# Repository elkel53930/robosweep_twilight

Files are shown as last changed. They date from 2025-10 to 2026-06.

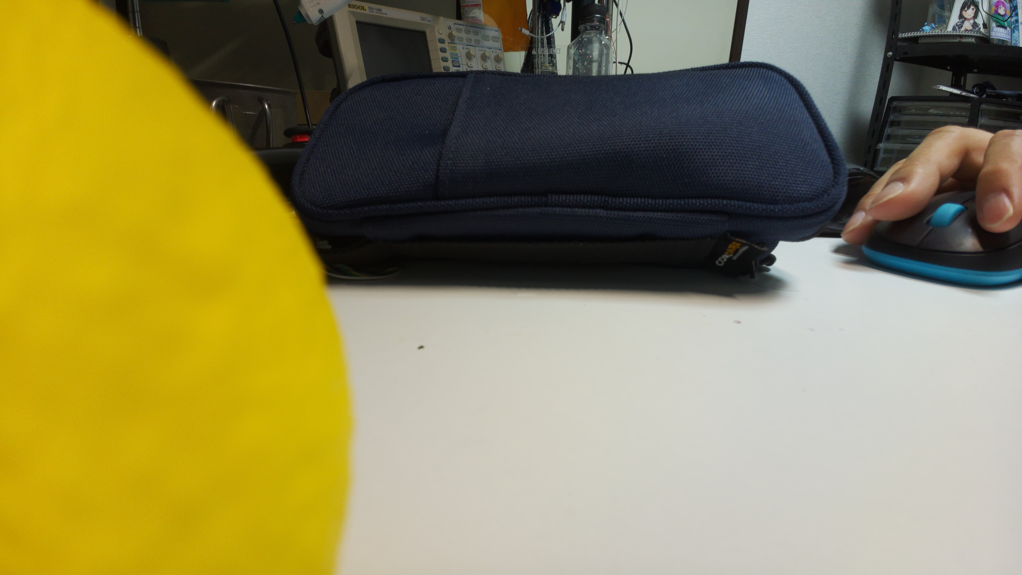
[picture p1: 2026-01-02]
software/rpi/camera_py/test.jpg

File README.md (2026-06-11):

# RoboSweep エージェント Twilight



[RoboSweepプレ大会](https://ntf.or.jp/robosweep/contest/contest2025/)で準優勝したチームからくり工房A:Macのエージェント(ロボット)Twilightのリポジトリです。

CADデータは[こちら](https://a360.co/4pVUIVw))

# ブロック図



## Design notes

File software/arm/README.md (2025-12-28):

# Arduino Nano Arm Board Controller

Arduino Nanoを使用したロボットアーム制御システムです。シリアル通信でサーボモータとDCモータを制御し、INA219センサーによるリアルタイム電流監視とmatplotlibによるグラフ表示機能を提供します。

## システム構成

### Arduino側（arm_board.ino）
- **D8, D9**: PWMサーボモータ（個別デフォルト角度: Servo1=80°, Servo2=180°）
- **A4, A5**: I2C電流センサ（INA219）
- **A1**: バッテリー電圧監視（10:1分圧回路）
- **D3**: NチャンネルMOSFET経由PWMモータ制御（2kHz）
- **センサーデータ送信**: 25ms間隔（40Hz）

### PC側（Python）
- `arm_board_controller.py`: メイン制御クラス
- `test.py`: インタラクティブ制御とファイル実行機能
- `throw_test.py`: 複雑な自動シーケンス実行
- `arm_board_test.py`: 基本機能テスト

## 通信プロトコル

### 制御コマンド（PC → Arduino）
```
S1<angle>       # サーボ1角度設定（即座に移動）(例: S1090 = 90度)
S2<angle>       # サーボ2角度設定（即座に移動）(例: S2180 = 180度)
S1A<angle>,<speed>  # サーボ1角度と速度設定 (例: S1A090,030 = 90度に30°/secで移動)
S2A<angle>,<speed>  # サーボ2角度と速度設定 (例: S2A180,060 = 180度に60°/secで移動)
S1S<speed>      # サーボ1デフォルト速度設定 (例: S1S045 = 45°/sec)
S2S<speed>      # サーボ2デフォルト速度設定 (例: S2S090 = 90°/sec)
M<speed>        # モータ速度設定 (例: M050 = 50%)
STATUS          # センサーデータ要求
STOP            # 緊急停止
```

**速度指定について:**
- 速度は1-180 degrees/secの範囲で指定
- デフォルト速度は180°/sec（最高速度）
- 速度制御は5ms間隔（200Hz）で更新

### 応答（Arduino → PC）
```
OK:<command>:<value>                    # コマンド成功
ERROR:<message>                         # エラー
DATA:<battery>,<current>,<power>        # センサーデータ（25ms毎、40Hz）
DEBUG:<message>                         # デバッグメッセージ
```

## セットアップ

### 必要なライブラリ

#### Arduino側
```cpp
#include <Wire.h>
#include <Servo.h>
#include <Adafruit_INA219.h>  // Adafruit INA219ライブラリが必要
```

Arduino IDEのライブラリマネージャーから「Adafruit INA219」をインストールしてください。

#### Python側
```bash
pip install pyserial matplotlib
```

### ハードウェア接続

1. **サーボモータ**: D8, D9ピンに接続
2. **電流センサ（INA219）**: A4(SDA), A5(SCL)に接続
3. **バッテリー監視**: A1ピンに10:1分圧回路で接続
4. **DCモータ**: D3ピンにMOSFET経由で接続

## 使用方法

### 1. 基本的な制御

```python
from arm_board_controller import ArmBoardController

# コントローラー初期化
controller = ArmBoardController('/dev/ttyUSB0')

if controller.connect():
    # サーボ制御（即座に移動）
    controller.set_servo1_angle(90)   # サーボ1を90度に
    controller.set_servo2_angle(45)   # サーボ2を45度に
    
    # サーボ速度制御
    controller.set_servo1_angle_with_speed(180, 30)  # 180度に30°/secで移動
    controller.set_servo2_angle_with_speed(0, 60)    # 0度に60°/secで移動
    
    # デフォルト速度設定
    controller.set_servo1_speed(45)   # サーボ1のデフォルト速度を45°/sec
    controller.set_servo2_speed(90)   # サーボ2のデフォルト速度を90°/sec
    
    # モータ制御
    controller.set_motor_speed(30)    # モータを30%の速度で回転
    
    # センサーデータ取得
    data = controller.get_latest_sensor_data()
    if data:
        print(f"Battery: {data.battery_voltage:.2f}V")
        print(f"Current: {data.current_mA:.1f}mA")
        print(f"Power: {data.power_mW:.1f}mW")
    
    controller.disconnect()
```

### 2. コンテキストマネージャー使用

```python
with ArmBoardController('/dev/ttyUSB0') as controller:
    controller.set_servo1_angle(90)
    controller.set_motor_speed(50)
    time.sleep(5)
    # 自動的に切断される
```

### 3. リアルタイムデータ監視とグラフ表示

```python
def sensor_callback(data):
    print(f"Battery: {data.battery_voltage:.2f}V, "
          f"Current: {data.current_mA:.1f}mA")

controller = ArmBoardController('/dev/ttyUSB0')
controller.connect()
controller.set_sensor_callback(sensor_callback)

# データは25ms毎にコールバックで受信される（40Hz）
time.sleep(10)
controller.disconnect()
```

### 4. ファイル実行でのリアルタイムプロット

ファイル実行モード時は自動的にmatplotlibグラフが表示されます：
- 上段：電流の生データ（青線）
- 下段：10ポイント移動平均（赤線）
- 時間軸：HH:MM:SS形式
- 自動スケーリング対応

## 新機能

### 1. 高速センサーデータ取得
- センサーデータ送信間隔：25ms（40Hz）
- サーボ制御更新間隔：5ms（200Hz）
- より細かい制御とデータ取得が可能

### 2. ファイル実行システム
- テキストファイルからコマンド読み込み
- ステップバイステップ実行
- 自動ループ機能
- コメント対応（#で始まる行）

### 3. リアルタイムグラフ監視
- matplotlib による電流値の可視化
- 移動平均によるノイズ除去
- 非ブロッキングプロット表示

### 4. 複雑な自動化シーケンス
- 電流値による条件判定
- 移動平均による電流変化の監視
- タイムアウト保護機能

## テストスクリプト

### インタラクティブ制御
```bash
python3 test.py
```

インタラクティブモードでは以下のコマンドが使用できます：
- `s1 90`: サーボ1を90度に設定（即座）
- `s2 180`: サーボ2を180度に設定（即座）
- `s1s 90 30`: サーボ1を90度に30°/secで移動
- `s2s 180 60`: サーボ2を180度に60°/secで移動
- `m 50`: モータを50%の速度に設定
- `stop`: 緊急停止
- `status`: センサーデータ表示
- `file <filename>`: テキストファイルからコマンド実行
- `sample`: サンプルコマンドファイル作成
- `help`: ヘルプ表示
- `quit`: 終了

### ファイル実行機能
```bash
# サンプルファイル作成
>>> sample
# ファイル実行（ステップバイステップ）
>>> file sample_commands.txt
```

ファイル実行モードでは：
- エンターキーで次のコマンドを実行
- 最後まで実行すると自動的にループ
- リアルタイム電流監視グラフ表示
- `q`で終了

### 自動化テストシーケンス
```bash
python3 throw_test.py
```

複雑な動作シーケンスを自動実行：
- サーボの段階的制御
- 電流監視と閾値判定
- 移動平均による電流変化の検出
- タイムアウト保護機能

### 基本制御テスト
```bash
python3 arm_board_test.py
```

## 安全機能

- 角度制限: サーボ角度は0-180度に自動制限
- 速度制限: モータ速度は0-100%に自動制限  
- 緊急停止: `STOP`コマンドですべてのモータを停止
- デフォルト位置復帰: 緊急停止時にServo1=80°、Servo2=180°に復帰
- 接続監視: 通信エラー時の自動復旧
- タイムアウト保護: 長時間処理での自動継続

## ファイルフォーマット

### コマンドファイル例（sample_commands.txt）
```
# Comment lines start with #
s1 180          # Set servo1 to 180 degrees instantly  
s2s 0 10        # Move servo2 to 0 degrees at 10°/sec
s1 45           # Set servo1 to 45 degrees
m 50            # Set motor to 50% speed
m 0             # Stop motor
stop            # Emergency stop
```

## トラブルシューティング

### INA219が見つからない場合
```
Failed to find INA219 chip - continuing without current sensor
```
- 配線を確認（VCC、GND、SDA=A4、SCL=A5）
- I2Cアドレスが0x40であることを確認
- `scanI2CDevices()`でI2Cデバイスをスキャン

### シリアル通信エラー
- ポート名を確認（`/dev/ttyUSB0`, `/dev/ttyACM0`など）
- ボーレートが115200であることを確認
- 他のプログラムがポートを使用していないか確認

### PWM周波数の変更
現在2kHzに設定されています。変更する場合は`setupMotorPWM()`関数を編集してください。

## ライセンス

このプロジェクトはMITライセンスの下で公開されています。

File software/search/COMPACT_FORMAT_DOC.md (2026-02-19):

# マイクロマウス迷路データ コンパクト形式 仕様書

## 概要

本ドキュメントでは、マイクロマウス迷路データの圧縮保存・転送を目的とした2つのコンパクト形式について説明します。

- **コンパクト形式**: 16進数ベースで中程度の圧縮率を実現し、デバッグ時にも内容を確認できる形式
- **ウルトラコンパクト形式**: バイナリ+Base64でMaximum圧縮を実現し、ネットワーク転送に最適化された形式

## 従来形式との比較

| 形式 | サイズ例（16x16迷路） | 圧縮率 | 可読性 | 用途 |
|---|---|---|---|---|
| 従来ASCII | 1122 bytes | 100% | ★★★ | 人間による編集・確認 |
| コンパクト | 528 bytes | 47.1% | ★☆☆ | デバッグ可能な圧縮保存 |
| ウルトラコンパクト | 352 bytes | 31.4% | ☆☆☆ | 最大圧縮・ネットワーク転送 |

---

## 1. コンパクト形式（Compact Format）

### 仕様

**対象サイズ**: 最大99x99の迷路まで対応

**フォーマット構造**:
```
[サイズ2桁][壁データ][|][観測データ][|G座標4桁][|S座標5桁]
```

### エンコード詳細

#### ヘッダー部
- **サイズ**: 2桁の10進数（ゼロパディング）
  - 例: `16` → 16x16迷路

#### 壁データ部
各セルの壁情報を4ビットの16進数1文字で表現：
```
ビット配置: [WEST|SOUTH|EAST|NORTH]
```
- bit 0 (0x1): 北の壁
- bit 1 (0x2): 東の壁  
- bit 2 (0x4): 南の壁
- bit 3 (0x8): 西の壁

セルの走査順序: `y=0,x=0` → `y=0,x=1` → ... → `y=size-1,x=size-1`

#### 観測データ部
壁データと同じ形式で、各方向が観測済みかどうかを記録

#### オプション部
- **ゴール**: `|G` + X座標2桁 + Y座標2桁
- **スタート**: `|S` + X座標2桁 + Y座標2桁 + 向き1桁

### エンコード例

```python
# 16x16迷路の例
"16c555545555455456ac55695556ad7a|eaaac515556a8542aaaa955447abafaaaaa|G0707|S00011"
```

分解すると:
- `16`: 16x16迷路
- `c555...`: 壁データ（256文字）
- `|eaaa...`: 観測データ（256文字） 
- `|G0707`: ゴール座標(7,7)
- `|S0001`: スタート座標(0,0)、向き1（東）

### 使用関数

```python
# エンコード
compact_str = write_maze_compact(known_walls, observed, goal, start_pose)

# デコード  
known_walls, observed, goal, start_pose = read_maze_compact(compact_str)

# Explorer経由
explorer = AdachiExplorer()
compact_data = explorer.export_compact()
goal = explorer.import_compact(compact_data)
```

---

## 2. ウルトラコンパクト形式（Ultra-Compact Format）

### 仕様

**対象サイズ**: 最大255x255の迷路まで対応

**エンコード**: バイナリデータをBase64エンコード

### バイナリ構造

```
[サイズ1byte][フラグ1byte][壁データ][観測データ][オプション]
```

#### ヘッダー部
1. **サイズ**: 1バイト（0-255）
2. **フラグ**: 1バイト
   - bit 0 (0x01): ゴール情報有り
   - bit 1 (0x02): スタート情報有り（デフォルトでない場合）
   - bit 2-7: 予約

#### データ部
**ビットパッキング**: 各セル4ビットを効率的にバイト境界で詰め込み

セル毎の壁情報（4ビット）:
```
[bit3:西|bit2:南|bit1:東|bit0:北]
```

パッキング例（16x16 = 256セル）:
- 256セル × 4ビット = 1024ビット = 128バイト（壁）
- 256セル × 4ビット = 1024ビット = 128バイト（観測）

#### オプション部
フラグに応じて追加:
- **ゴール** (2バイト): X座標 + Y座標
- **スタート** (3バイト): X座標 + Y座標 + 向き

### エンコード例

```python
# Base64エンコード結果例
"EANcVUVVVVRFZcpVllVl2qeuqlxRVaZYJKqqWUV0uvqqqopFpspRcaqrqq+qqlxVgiWapqqqy2Srr1..."
```

バイナリ構造:
```
0x10: サイズ（16）
0x03: フラグ（ゴール+スタート有り）
0x5c, 0x55, ...: ビットパックされた壁データ（128バイト）
0xea, 0xaa, ...: ビットパックされた観測データ（128バイト）  
0x07, 0x07: ゴール座標(7,7)
0x00, 0x00, 0x01: スタート座標(0,0)、向き1
```

### 使用関数

```python
# エンコード
ultra_str = write_maze_ultracompact(known_walls, observed, goal, start_pose)

# デコード
known_walls, observed, goal, start_pose = read_maze_ultracompact(ultra_str)

# Explorer経由
explorer = AdachiExplorer()
ultra_data = explorer.export_ultracompact()
goal = explorer.import_ultracompact(ultra_data)
```

---

## 3. 利用シーン別推奨事項

### コンパクト形式を推奨する場面
- ✅ ログファイルの圧縮保存
- ✅ デバッグ時に内容を確認したい場合
- ✅ ヒューマンリーダブルな圧縮が必要
- ✅ 中程度の圧縮で十分な場合

### ウルトラコンパクト形式を推奨する場面  
- ✅ ネットワーク経由での迷路データ転送
- ✅ 大量の迷路データのアーカイブ
- ✅ メモリ制約が厳しい組み込みシステム
- ✅ 最大限の圧縮率が必要な場合
- ✅ データベースでの大量保存

### 従来ASCII形式を推奨する場面
- ✅ 人間が直接編集する迷路ファイル
- ✅ 迷路の視覚的確認が必要
- ✅ 既存ツールとの互換性が必要
- ✅ 学習・デバッグ目的での利用

---

## 4. 実装上の注意点

### エラーハンドリング
```python
try:
    data = write_maze_compact(walls, obs, goal, pose)
    walls, obs, goal, pose = read_maze_compact(data)
except ValueError as e:
    print(f"フォーマットエラー: {e}")
```

### サイズ制限
- **コンパクト形式**: 99x99まで
- **ウルトラコンパクト形式**: 255x255まで
- 制限を超えるとValueErrorが発生

### パフォーマンス特性
- **エンコード**: O(size²) 
- **デコード**: O(size²)
- **メモリ使用量**: O(size²)

---

## 5. テスト・検証

テストスクリプトでの検証:
```bash
cd software/search
python3 test_step_solver.py --compact-test maze_data/file.txt --verbose
```

出力例:
```
[INFO] Compact encoded (528 bytes): 16c555545555455456ac...
[INFO] Ultra-compact encoded (352 bytes): EANcVUVVVVRFZcpV...
[INFO] Size comparison: original=1122 bytes, compact=528 bytes (47.1%), ultra-compact=352 bytes (31.4%)
```

### 検証内容
1. エンコード/デコードの可逆性
2. 壁データの完全性
3. 観測データの完全性  
4. ゴール・スタート位置の保持
5. 圧縮率の測定

---

## 6. 今後の拡張可能性

### 追加可能な機能
- 距離情報の埋め込み
- 探索履歴の圧縮保存
- カスタムメタデータの追加
- より高度な圧縮アルゴリズムの適用

### 互換性の維持
- フォーマットバージョニング
- 下位互換性の保証
- 段階的な機能追加

---

## リファレンス

### 関数一覧

| 関数名 | 説明 | 戻り値 |
|---|---|---|
| `write_maze_compact()` | コンパクト形式エンコード | str |
| `read_maze_compact()` | コンパクト形式デコード | tuple |
| `write_maze_ultracompact()` | ウルトラコンパクト形式エンコード | str |
| `read_maze_ultracompact()` | ウルトラコンパクト形式デコード | tuple |
| `BaseExplorer.export_compact()` | エクスプローラーからエクスポート | str |
| `BaseExplorer.import_compact()` | エクスプローラーへインポート | tuple[int,int]\|None |
| `BaseExplorer.export_ultracompact()` | ウルトラコンパクトエクスポート | str |
| `BaseExplorer.import_ultracompact()` | ウルトラコンパクトインポート | tuple[int,int]\|None |

### ファイル構成
- `micromouse_algorithms.py`: メイン実装
- `test_step_solver.py`: テスト・検証機能
- このドキュメント: `COMPACT_FORMAT_DOC.md`

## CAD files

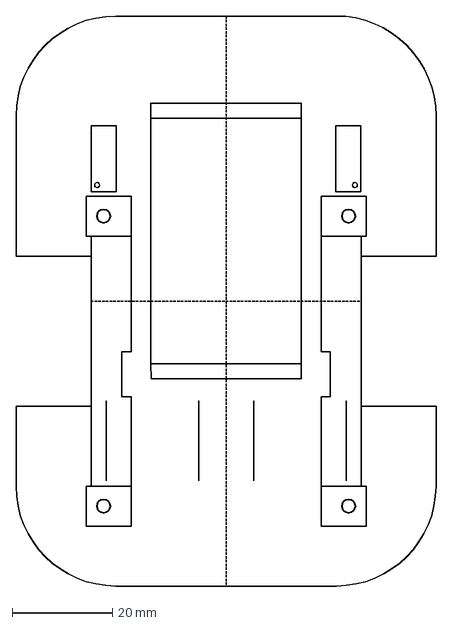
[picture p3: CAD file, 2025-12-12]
elec/main_board/main_board_outline.dxf
84.0 x 114.0 mm

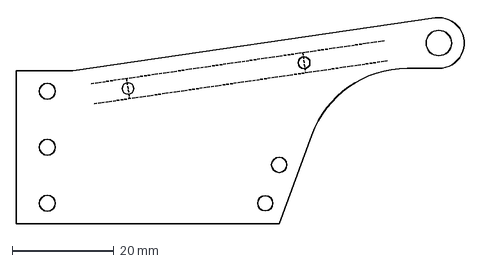
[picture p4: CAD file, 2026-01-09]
elec/arm_board/arm_board_outline.dxf
88.4 x 40.7 mm

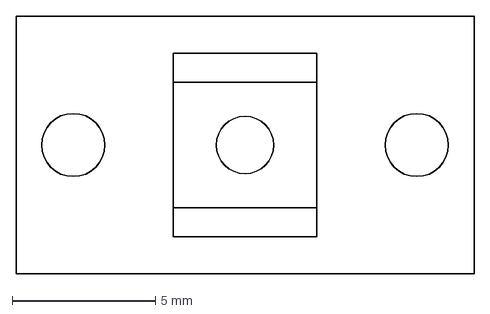
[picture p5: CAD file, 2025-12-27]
elec/sub_boards/encoder_board_outline.dxf
16.0 x 9.00 mm

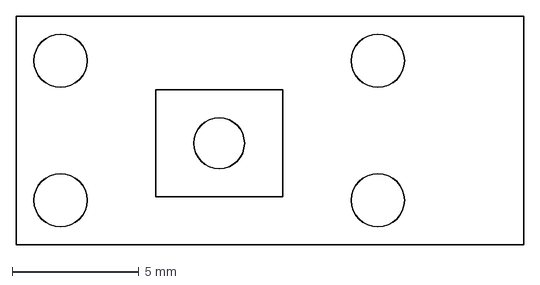
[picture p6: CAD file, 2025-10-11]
elec/main_board/encoder_board_outline.dxf
20.0 x 9.00 mm

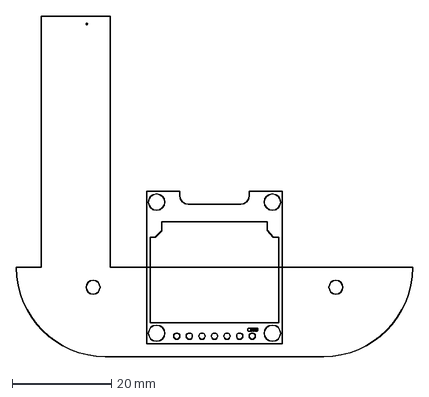
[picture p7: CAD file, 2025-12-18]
elec/sub_boards/if_sub_board_outline.dxf
80.0 x 68.6 mm

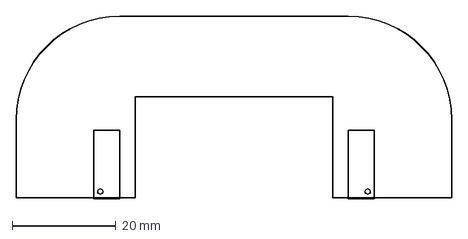
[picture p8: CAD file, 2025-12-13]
elec/sub_boards/sensor_sub_board_outline.dxf
84.0 x 35.2 mm

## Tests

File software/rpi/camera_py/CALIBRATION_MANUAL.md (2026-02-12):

# ボール検出キャリブレーションマニュアル

## 概要

`manual_calibration.py`は、カメラとボール検出アルゴリズムのキャリブレーションデータを収集するためのGUIアプリケーションです。実際のボール位置と検出結果を記録し、距離・角度の推定精度を向上させるためのデータを蓄積します。

## 動作環境

- Raspberry Pi 5
- Picamera2対応カメラ
- Python 3.x
- 必要なライブラリ：tkinter, cv2, numpy, PIL, picamera2
- アームコントローラー（オプション）

## セットアップ

### 1. ディレクトリ移動

```bash
cd /home/k-iida/dev/robosweep_twilight/software/rpi/camera_py
```

### 2. アプリケーション起動

```bash
python3 manual_calibration.py
```

起動時に以下の処理が自動で実行されます：
- カメラの初期化
- アームサーボのトルクON
- アームを走行位置（RUN_POSITION = -90度）に移動
- 距離と角度の初期値設定（距離: 100mm、角度: 0.0πrad）

## 操作手順

### 基本的なキャリブレーションフロー

1. **ボールの配置**
   - カメラの前にボールを配置します
   - メジャーなどで正確な距離と角度を測定します

2. **距離・角度の入力**
   - 「距離 (mm)」: ロボット中心からボール中心までの距離をミリメートルで入力
   - 「角度 (πrad)」: ロボット正面からの角度をπラジアン単位で入力
     - 例：正面 = 0.0、右30度 ≈ 0.1667、右90度 = 0.5
   - 初回起動時は自動で「100mm」「0.0πrad」が入力されています
   - 値は手動で編集可能です

3. **計測開始**
   - 「計測開始」ボタンをクリック
   - アプリが自動的に10回ボールを検出します
   - 計測進捗が「0 / 10」から「10 / 10」まで更新されます

4. **結果の確認**
   - 計測完了後、以下の中央値が表示されます：
     - **検出直径 (px)**: 画像上のボール直径（ピクセル）
     - **位置X (px)**: ボール中心のX座標（ピクセル）
     - **位置Y (px)**: ボール中心のY座標（ピクセル）
     - **計算角度 (πrad)**: アルゴリズムが計算した角度
     - **計算距離 (mm)**: アルゴリズムが計算した距離

5. **データ保存**
   - 結果が妥当であれば「OK - CSVに保存」ボタンをクリック
   - データが`calibration_data.csv`に追記されます
   - 保存後、次の計測値が自動的に入力されます：
     - 通常：距離 +20mm、角度は同じ
     - 距離が260mm以上の場合：距離を100mmに戻し、角度 +0.025πrad

6. **繰り返し**
   - ボールを新しい位置に移動
   - 手順2に戻る

### 計測のキャンセル

計測結果が不適切な場合：
- 「キャンセル」ボタンをクリック
- 計測データがリセットされます
- 入力値はそのまま残ります

## GUI説明

### カメラ映像表示エリア

- リアルタイムのカメラ映像を表示
- 検出されたボールには緑色の円が描画されます
- ボール中心には赤い点が表示されます
- 画面左上に検出情報（半径、信頼度）が表示されます

### 入力エリア

| 項目 | 説明 | 単位 |
|---|---|---|
| 距離 | ロボット中心からボール中心までの実測距離 | mm |
| 角度 | ロボット正面からの角度（右回り正） | πrad |

### 計測結果エリア

| 項目 | 説明 | 単位 |
|---|---|---|
| 計測進捗 | 10回計測のうち何回完了したか | - |
| 検出直径 | 画像上で検出されたボールの直径（中央値） | px |
| 位置X | 画像上のボール中心X座標（中央値） | px |
| 位置Y | 画像上のボール中心Y座標（中央値） | px |
| 計算角度 | アルゴリズムが計算した角度（中央値） | πrad |
| 計算距離 | アルゴリズムが計算した距離（中央値） | mm |

## 角度の単位について

このアプリケーションでは角度を**πラジアン**単位で扱います。

### πラジアンとは

- 180度 = 1π ラジアン = 1.0 πrad
- 90度 = 0.5π ラジアン = 0.5 πrad
- 30度 = π/6 ラジアン ≈ 0.1667 πrad
- -90度 = -0.5π ラジアン = -0.5 πrad

### 変換式

```
度 → πラジアン: πrad = 度 / 180
πラジアン → 度: 度 = πrad × 180
```

### 例

| 度 | πラジアン |
|----|---|
| 0° | 0.0000 |
| 15° | 0.0833 |
| 30° | 0.1667 |
| 45° | 0.2500 |
| 90° | 0.5000 |
| -30° | -0.1667 |
| -90° | -0.5000 |

## 自動値更新機能

効率的なデータ収集のため、CSV保存後に次の計測値が自動設定されます。

### 更新ルール

1. **通常の場合**
   - 距離：現在値 + 20mm
   - 角度：変更なし
   - 例：100mm → 120mm → 140mm → ... → 260mm

2. **距離が260mm以上に達した場合**
   - 距離：100mmにリセット
   - 角度：現在値 + 0.025πrad（約4.5度）
   - 例：260mm, 0.0πrad → 100mm, 0.025πrad

### キャリブレーションパターン例

```
角度 0.000πrad: 100, 120, 140, 160, 180, 200, 220, 240, 260mm
角度 0.025πrad: 100, 120, 140, 160, 180, 200, 220, 240, 260mm
角度 0.050πrad: 100, 120, 140, 160, 180, 200, 220, 240, 260mm
...
```

## CSV出力フォーマット

データは`calibration_data.csv`に保存されます。

### フィールド一覧

| フィールド名 | 説明 | 単位 |
|---|---|---|
| timestamp | データ取得日時 | YYYY-MM-DD HH:MM:SS |
| input_distance_mm | 入力した実測距離 | mm |
| input_angle_pi_rad | 入力した実測角度 | πrad |
| detected_diameter_px | 検出されたボール直径 | px |
| detected_x_px | 検出されたボールX座標 | px |
| detected_y_px | 検出されたボールY座標 | px |
| calc_angle_pi_rad | 計算された角度 | πrad |
| calc_distance_mm | 計算された距離 | mm |

### CSVファイル例

```csv
timestamp,input_distance_mm,input_angle_pi_rad,detected_diameter_px,detected_x_px,detected_y_px,calc_angle_pi_rad,calc_distance_mm
2026-02-12 14:30:15,100,0.0000,85.50,320.00,180.00,0.0012,102.34
2026-02-12 14:31:22,120,0.0000,71.25,318.50,182.00,-0.0015,118.67
2026-02-12 14:32:10,140,0.0000,60.80,321.00,181.50,0.0008,142.89
```

## トラブルシューティング

### カメラが起動しない

- Picamera2が正しくインストールされているか確認
- カメラケーブルの接続を確認
- 他のアプリケーションがカメラを使用していないか確認

### ボールが検出されない

- ボールの色がHSV設定範囲内か確認
- 照明条件を調整
- ボールとの距離が適切か確認（近すぎ・遠すぎないか）
- `ball_detect.py`のHSVパラメータを調整

### アーム初期化エラー

- アームコントローラーの接続を確認（`/dev/ttyAMA0`, `/dev/ttyARM`）
- シリアルポートの権限を確認
- 警告が表示されてもアームなしで続行可能です

### 計測が10回完了しない

- ボールがカメラ視野内にあるか確認
- ボールが他の物体で遮られていないか確認
- 照明条件を改善

## 終了方法

1. 「終了」ボタンをクリック
2. 以下の処理が自動で実行されます：
   - カメラ停止
   - アームサーボのトルクOFF
   - リソース解放

または、ウィンドウの×ボタンで閉じることもできます。

## 推奨キャリブレーション手順

### 1. グリッド配置法

ロボットの前方に格子状にボールを配置してデータを収集します。

**距離範囲**: 100mm ～ 260mm（20mm間隔）  
**角度範囲**: -0.5πrad ～ 0.5πrad（0.025πrad間隔）

合計データ点数：約9距離 × 41角度 = 369点

### 2. データ収集のコツ

- 照明を一定に保つ
- ボールの高さを地面から35mm（ボール半径）に保つ
- 計測ごとにボール位置を正確に測定
- カメラレンズの汚れを事前に清掃

### 3. 品質チェック

- 実測値と計算値の差を確認
- 異常値がないかチェック
- 必要に応じて再計測

## ファイル構成

```
rpi/camera_py/
├── manual_calibration.py      # キャリブレーションアプリ本体
├── ball_detect.py              # ボール検出モジュール
├── calibration_data.csv        # キャリブレーションデータ（出力）
└── CALIBRATION_MANUAL.md       # このマニュアル
```

## 関連ファイル

- `ball_detect.py`: ボール検出アルゴリズム実装
- `ball_detect_threaded.py`: スレッド化されたボール検出
- `../../arm/arm.py`: アームコントローラー

## 更新履歴

- 2026-02-12: 初版作成
  - 基本機能実装
  - 自動値更新機能追加
  - πラジアン単位採用
  - アーム連携機能追加

## ライセンス・連絡先

プロジェクト内部ドキュメント

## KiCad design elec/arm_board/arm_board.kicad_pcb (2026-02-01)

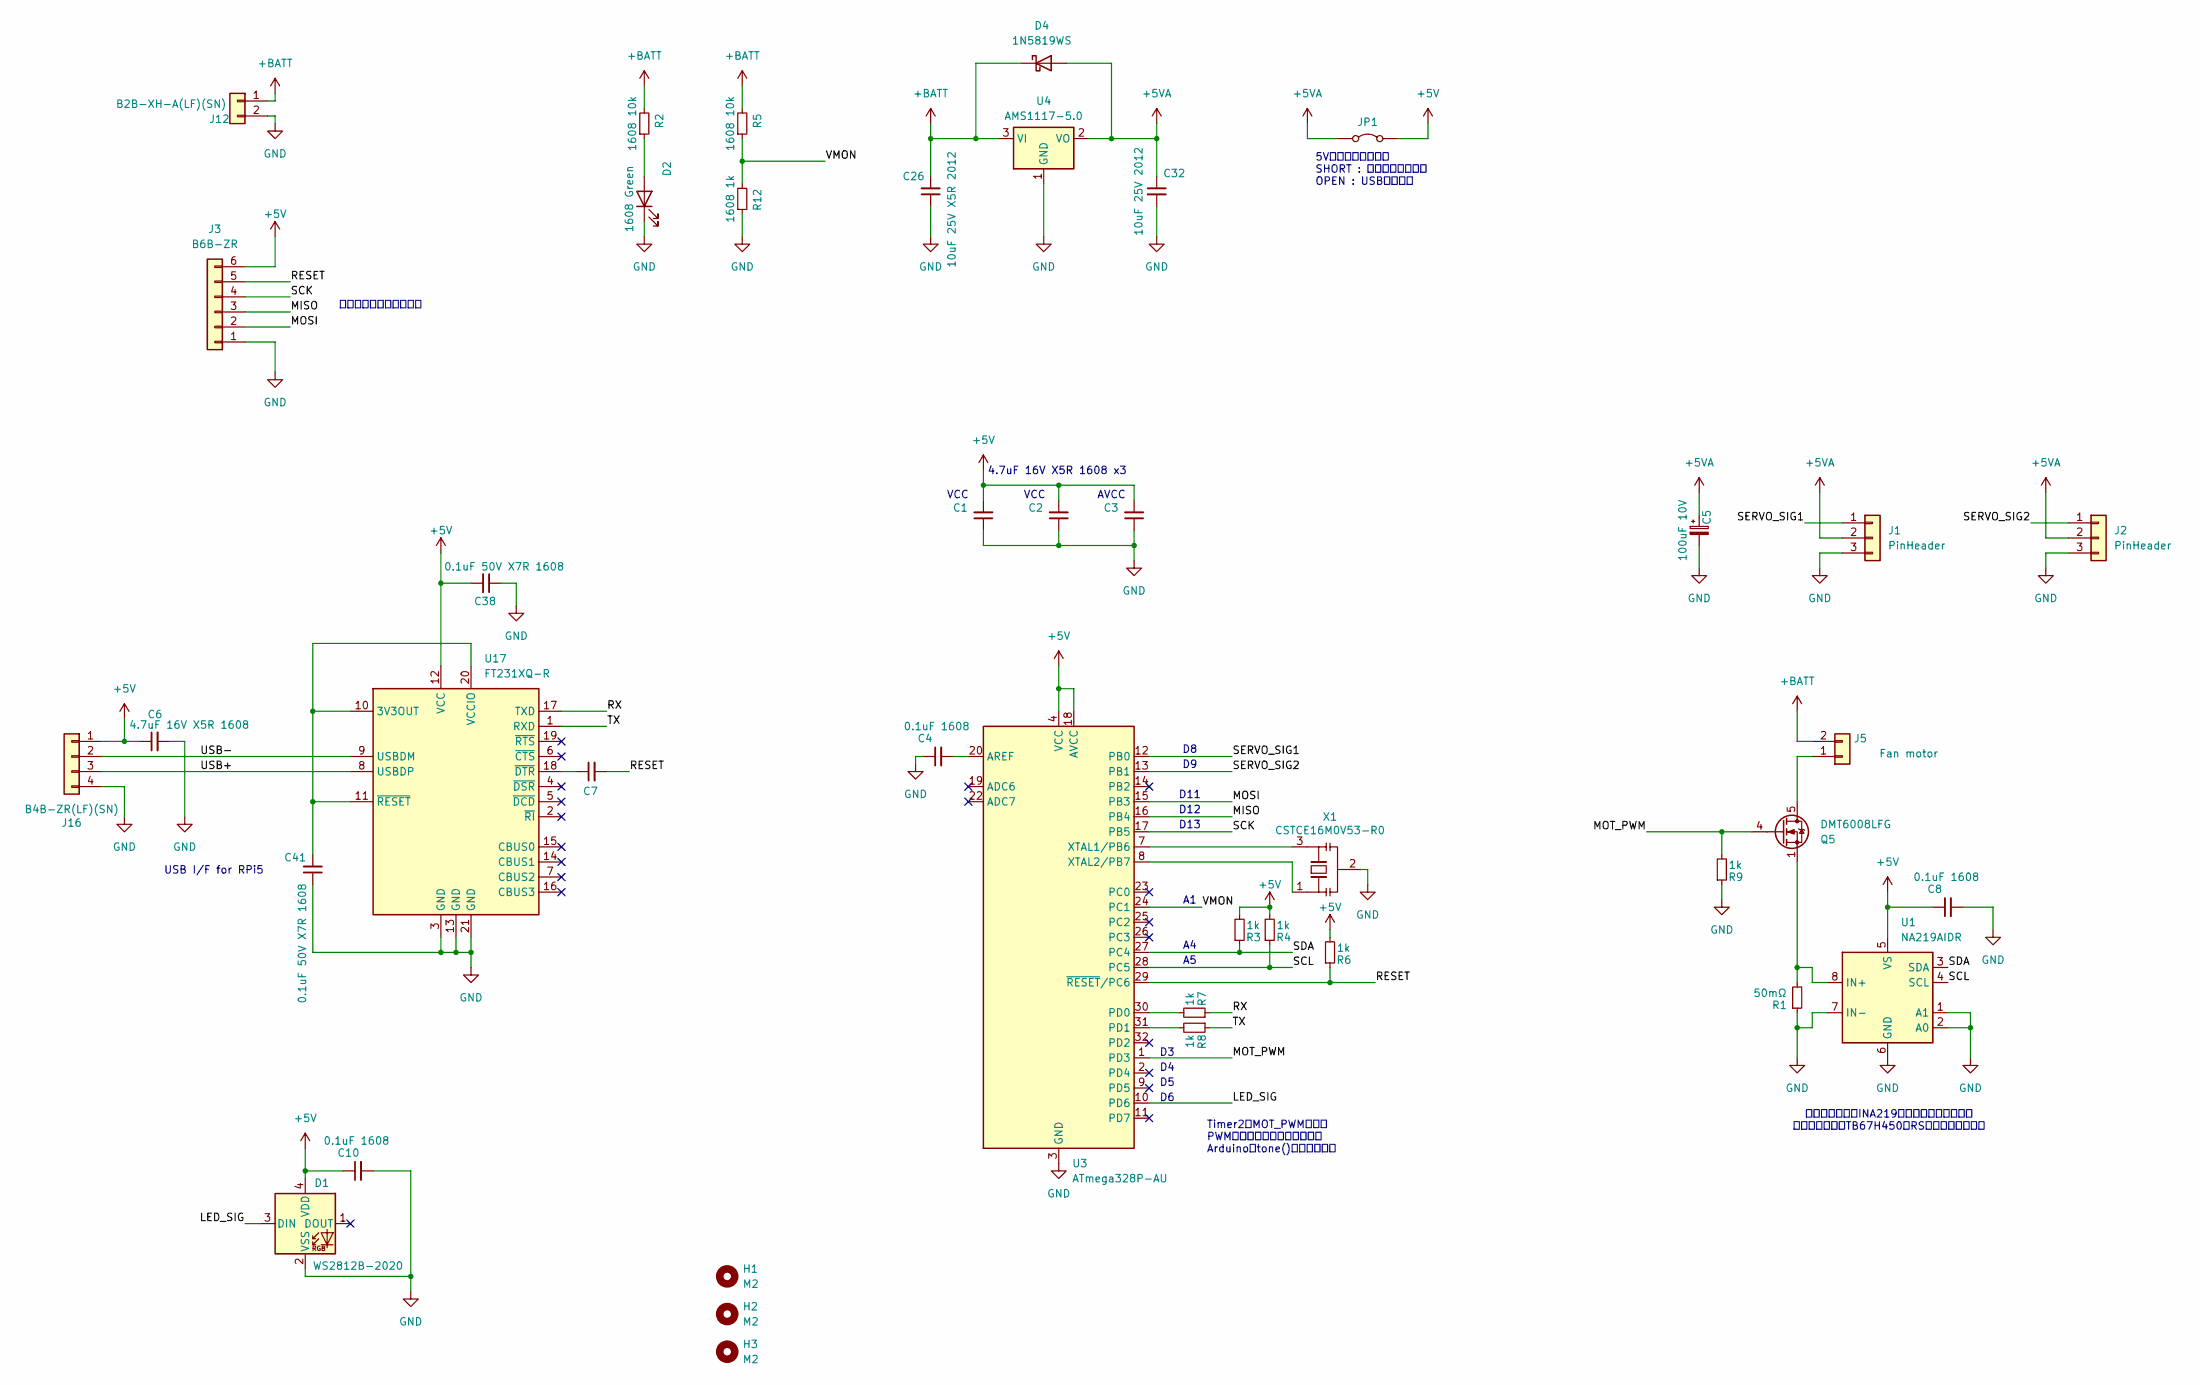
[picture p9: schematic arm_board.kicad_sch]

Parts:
C1, C2, C3, C6: CL10A475KO8NNNC; C_0603_1608Metric
C4, C7, C8, C10, C38, C41: CC0603KRX7R9BB104; C_0603_1608Metric
C5: RVT1A101M0505; CP_Elec_5x5.4
C26, C32: CL21A106KAYNNNE; C_0805_2012Metric
D1: WS2812B-2020; LED_WS2812B-2020_PLCC4_2.0x2.0mm
D2: D-060306G1/SS2/G1; LED_0603_1608Metric
D4: 1N5819WS; D_SOD-323
H1, H2, H3: M2; MountingHole_2.2mm_M2
J1, J2: PinHeader; PinHeader_1x03_P2.54mm_Vertical
J3: B6B-ZR; JST_ZH_B6B-ZR_1x06_P1.50mm_Vertical
J5: Fan motor; PinHeader_1x02_P2.54mm_Vertical
J12: B2B-XH-A(LF)(SN); JST_XH_B2B-XH-AM_1x02_P2.50mm_Vertical
J16: B4B-ZR(LF)(SN); JST_ZH_B4B-ZR_1x04_P1.50mm_Vertical
JP1: Switch 5V supply; PinHeader_1x02_P2.54mm_Vertical
Q5: DMT6008LFG; Diodes_PowerDI3333-8
R1: 25121WF500MT4E; D_2512_6332Metric
R2, R5: 0603WAF1002T5E; R_0603_1608Metric
R3, R4, R6, R7, R8, R9, R12: 0603WAF1001T5E; R_0603_1608Metric
U1: NA219AIDR; SOIC-8_3.9x4.9mm_P1.27mm
U3: ATmega328P-AU; TQFP-32_7x7mm_P0.8mm
U4: AMS1117-5.0; SOT-223-3_TabPin2
U17: FT231XQ-R; QFN-20-1EP_4x4mm_P0.5mm_EP2.5x2.5mm
X1: CSTCE16M0V53-R0; Resonator_SMD_Murata_CSTxExxV-3Pin_3.0x1.1mm

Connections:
+5V: C1.2, C2.2, C3.2, C6.1, C8.1, C10.1, C38.2, D1.4 (VDD), J3.6, J16.1, JP1.2 (B), R3.2, R4.2, R6.2, U1.5 (VS), U3.4 (VCC), U3.6 (VCC), U3.18 (AVCC), U17.12 (VCC)
+5VA: C5.1, C32.1, D4.2 (A), J1.2, J2.2, JP1.1 (A), U4.2 (VO)
+BATT: C26.2, D4.1 (K), J5.2, J12.1, R2.2, R5.2, U4.3 (VI)
/LED_SIG: D1.3 (DIN), U3.10 (PD6)
/MISO: J3.3, U3.16 (PB4)
/MOSI: J3.2, U3.15 (PB3)
/MOT_PWM: Q5.4 (G), R9.2, U3.1 (PD3)
/RESET: C7.2, J3.5, R6.1, U3.29 (~RESET/PC6)
/RX: R7.1, U17.17 (TXD)
/SCK: J3.4, U3.17 (PB5)
/SCL: R4.1, U1.4 (SCL), U3.28 (PC5)
/SDA: R3.1, U1.3 (SDA), U3.27 (PC4)
/SERVO_SIG1: J1.1, U3.12 (PB0)
/SERVO_SIG2: J2.1, U3.13 (PB1)
/TX: R8.1, U17.1 (RXD)
/USB+: J16.3, U17.8 (USBDP)
/USB-: J16.2, U17.9 (USBDM)
/VMON: R5.1, R12.2, U3.24 (PC1)
GND: C1.1, C2.1, C3.1, C4.1, C5.2, C6.2, C8.2, C10.2, C26.1, C32.2, C38.1, C41.1, D1.2 (VSS), D2.1 (K), J1.3, J2.3, J3.1, J12.2, J16.4, R1.1, R9.1, R12.1, U1.1 (A1), U1.2 (A0), U1.6 (GND), U1.7 (IN-), U3.3 (GND), U3.5 (GND), U3.21 (GND), U4.1 (GND), U17.3 (GND), U17.13 (GND), U17.21 (GND), X1.2
unnamed: D2.2 (A), R2.1
unnamed: J5.1, Q5.5 (D)
unnamed: Q5.1 (S), Q5.2 (S), Q5.3 (S), R1.2, U1.8 (IN+)
unnamed: C4.2, U3.20 (AREF)
unnamed: R7.2, U3.30 (PD0)
unnamed: R8.2, U3.31 (PD1)
unnamed: U3.7 (XTAL1/PB6), X1.3
unnamed: U3.8 (XTAL2/PB7), X1.1
unnamed: C41.2, U17.10 (3V3OUT), U17.11 (~RESET), U17.20 (VCCIO)
unnamed: C7.1, U17.18 (~DTR)

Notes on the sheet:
AVCC
VCC
4.7uF 16V X5R 1608 x3
USB I/F for RPi5
D13
電流検出抵抗とINA219の間はケルビン接続。 電流検出抵抗はTB67H450のRSピン直近に配置。
D12
ブートローダー書込み用
5V電源の切り替え。 SHORT : 内蔵レギュレータ OPEN : USBコネクタ
D11
Timer2はMOT_PWMからの PWM信号生成に使用するため、 Arduinoのtone()は使用不可。

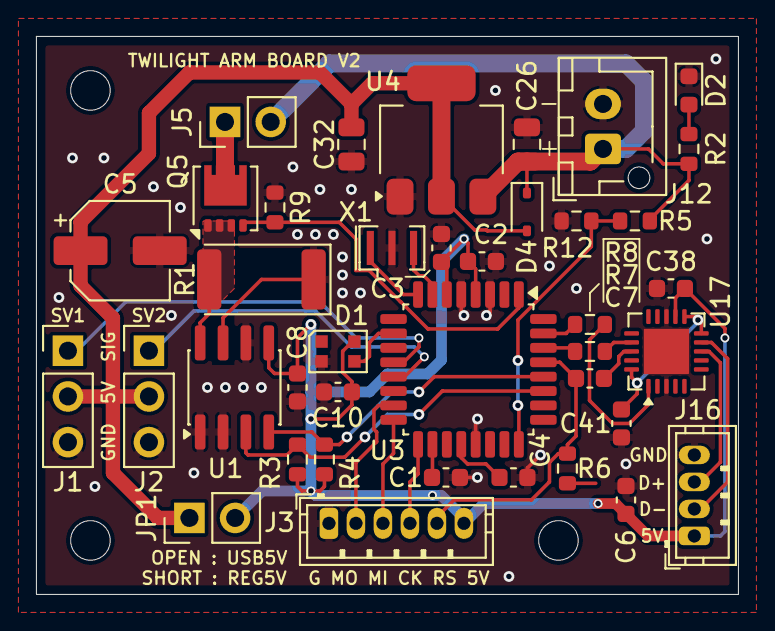
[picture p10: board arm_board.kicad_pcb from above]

Board: 2 copper layers, 39.0 x 31.0 mm, 42 parts (0 on the bottom side), 29 nets.

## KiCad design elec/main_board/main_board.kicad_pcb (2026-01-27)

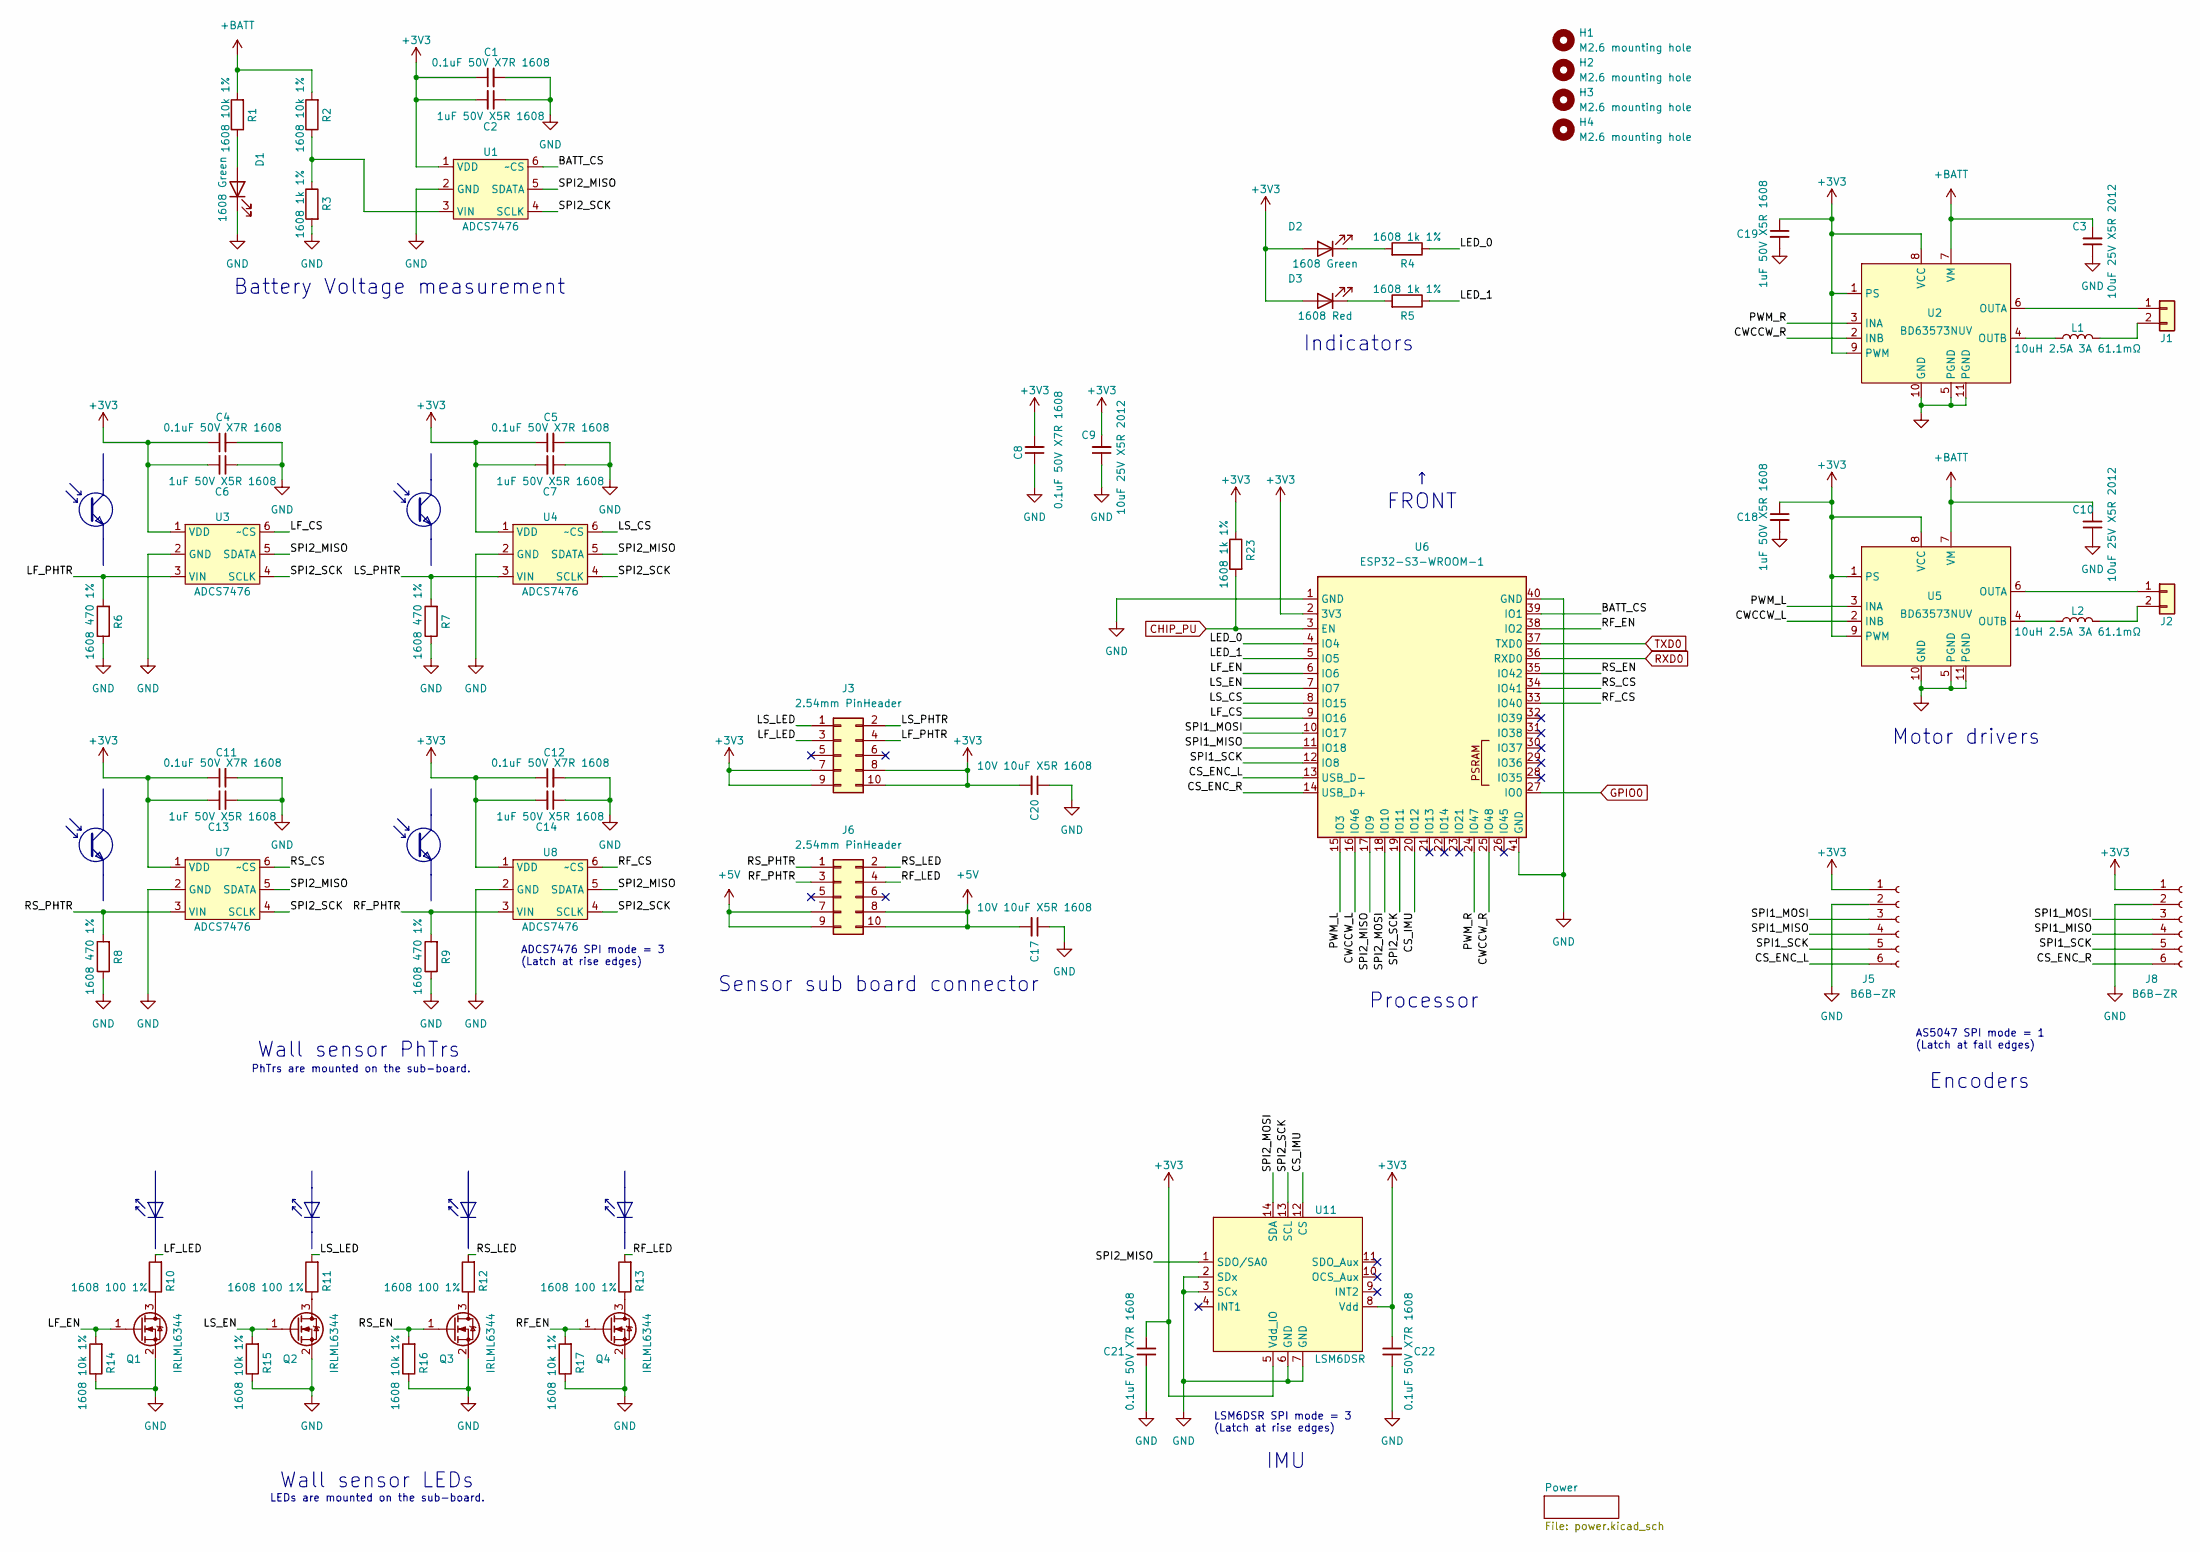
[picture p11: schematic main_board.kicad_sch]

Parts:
C1, C4, C5, C8, C11, C12, C21, C22: CC0603KRX7R9BB104; C_0603_1608Metric
C2, C6, C7, C13, C14, C18, C19: CL10A105KB8NNNC; C_0603_1608Metric
C3, C9, C10: CL21A106KAYNNNE; C_0805_2012Metric
C17, C20: CL10A106KP8NNNC; C_0603_1608Metric
D1, D2: D-060306G1/SS2/G1; LED_0603_1608Metric
D3: KT-0603R; LED_0603_1608Metric
H1, H2, H3, H4: M2.6 mounting hole; M2.6 Mounting Hole
J1, J2: Conn_01x02; PinHeader_1x02_P1.27mm_Vertical
J3, J6: 2.54mm PinHeader; PinHeader_2x05_P2.54mm_Vertical
J5, J8: B6B-ZR; JST_ZH_B6B-ZR_1x06_P1.50mm_Vertical
L1, L2: NR6045T100M; L_Changjiang_FNR6040S
Q1, Q2, Q3, Q4: IRLML6344; SOT-23
R1, R2, R14, R15, R16, R17: 0603WAF1002T5E; R_0603_1608Metric
R3, R4, R5, R23: 0603WAF1001T5E; R_0603_1608Metric
R6, R7, R8, R9: 0603WAF4700T5E; R_0603_1608Metric
R10, R11, R12, R13: 0603WAF1000T5E; R_0603_1608Metric
U1, U3, U4, U7, U8: ADCS7476; SOT-23-6
U2, U5: BD63573NUV; VSON-10-1EP_3x3mm_P0.5mm_EP1.2x2mm
U6: ESP32-S3-WROOM-1
U11: LSM6DSR; Bosch_LGA-14_3x2.5mm_P0.5mm

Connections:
+3V3: C1.1, C2.2, C4.1, C5.1, C6.2, C7.2, C8.2, C9.2, C11.1, C12.1, C13.2, C14.2, C18.1, C19.1, C20.2, C21.2, C22.2, D2.2 (A), D3.2 (A), J3.7, J3.8, J3.9, J3.10, J5.1, J8.1, R23.1, U1.1 (VDD), U2.1 (PS), U2.8 (VCC), U2.9 (PWM), U3.1 (VDD), U4.1 (VDD), U5.1 (PS), U5.8 (VCC), U5.9 (PWM), U6.2 (3V3), U7.1 (VDD), U8.1 (VDD), U11.5 (Vdd_IO), U11.8 (Vdd); also elsewhere on the board
+5V: C17.2, J6.7, J6.8, J6.9, J6.10; also elsewhere on the board
+BATT: C3.2, C10.2, R1.2, R2.2, U2.7 (VM), U5.7 (VM); also elsewhere on the board
/BATT_CS: U1.6 (~CS), U6.39 (IO1)
/CS_ENC_L: J5.6, U6.13 (USB_D-)
/CS_ENC_R: J8.6, U6.14 (USB_D+)
/CS_IMU: U6.20 (IO12), U11.12 (CS)
/CWCCW_L: U5.2 (INB), U6.16 (IO46)
/CWCCW_R: U2.2 (INB), U6.25 (IO48)
/LED_0: R4.1, U6.4 (IO4)
/LED_1: R5.1, U6.5 (IO5)
/LF_CS: U3.6 (~CS), U6.9 (IO16)
/LF_EN: Q1.1 (G), R14.2, U6.6 (IO6)
/LF_LED: J3.3, R10.2
/LF_PHTR: J3.4, R6.2, U3.3 (VIN)
/LS_CS: U4.6 (~CS), U6.8 (IO15)
/LS_EN: Q2.1 (G), R15.2, U6.7 (IO7)
/LS_LED: J3.1, R11.2
/LS_PHTR: J3.2, R7.2, U4.3 (VIN)
/PWM_L: U5.3 (INA), U6.15 (IO3)
/PWM_R: U2.3 (INA), U6.24 (IO47)
/RF_CS: U6.33 (IO40), U8.6 (~CS)
/RF_EN: Q4.1 (G), R17.2, U6.38 (IO2)
/RF_LED: J6.4, R13.2
/RF_PHTR: J6.3, R9.2, U8.3 (VIN)
/RS_CS: U6.34 (IO41), U7.6 (~CS)
/RS_EN: Q3.1 (G), R16.2, U6.35 (IO42)
/RS_LED: J6.2, R12.2
/RS_PHTR: J6.1, R8.2, U7.3 (VIN)
/SPI1_MISO: J5.4, J8.4, U6.11 (IO18)
/SPI1_MOSI: J5.3, J8.3, U6.10 (IO17)
/SPI1_SCK: J5.5, J8.5, U6.12 (IO8)
/SPI2_MISO: U1.5 (SDATA), U3.5 (SDATA), U4.5 (SDATA), U6.17 (IO9), U7.5 (SDATA), U8.5 (SDATA), U11.1 (SDO/SA0)
/SPI2_MOSI: U6.18 (IO10), U11.14 (SDA)
/SPI2_SCK: U1.4 (SCLK), U3.4 (SCLK), U4.4 (SCLK), U6.19 (IO11), U7.4 (SCLK), U8.4 (SCLK), U11.13 (SCL)
CHIP_PU: R23.2, U6.3 (EN); also elsewhere on the board
GND: C1.2, C2.1, C3.1, C4.2, C5.2, C6.1, C7.1, C8.1, C9.1, C10.1, C11.2, C12.2, C13.1, C14.1, C17.1, C18.2, C19.2, C20.1, C21.1, C22.1, D1.1 (K), J5.2, J8.2, Q1.2 (S), Q2.2 (S), Q3.2 (S), Q4.2 (S), R3.2, R6.1, R7.1, R8.1, R9.1, R14.1, R15.1, R16.1, R17.1, U1.2 (GND), U2.5 (PGND), U2.10 (GND), U2.11 (PGND), U3.2 (GND), U4.2 (GND), U5.5 (PGND), U5.10 (GND), U5.11 (PGND), U6.1 (GND), U6.40 (GND), U6.41 (GND), U7.2 (GND), U8.2 (GND), U11.2 (SDx), U11.3 (SCx), U11.6 (GND), U11.7 (GND); also elsewhere on the board
GPIO0: U6.27 (IO0); also elsewhere on the board
unnamed: D1.2 (A), R1.1
unnamed: D2.1 (K), R4.2
unnamed: D3.1 (K), R5.2
unnamed: J1.1, U2.6 (OUTA)
unnamed: J1.2, L1.2
unnamed: J2.1, U5.6 (OUTA)
unnamed: J2.2, L2.2
unnamed: Q1.3 (D), R10.1
unnamed: Q2.3 (D), R11.1
unnamed: Q3.3 (D), R12.1
unnamed: Q4.3 (D), R13.1
unnamed: R2.1, R3.1, U1.3 (VIN)
unnamed: L1.1, U2.4 (OUTB)
unnamed: L2.1, U5.4 (OUTB)
RXD0: U6.36 (RXD0); also elsewhere on the board
TXD0: U6.37 (TXD0); also elsewhere on the board

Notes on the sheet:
IMU
Wall sensor LEDs
PhTrs are mounted on the sub-board.
AS5047 SPI mode = 1 (Latch at fall edges)
Indicators
Processor
LEDs are mounted on the sub-board.
Battery Voltage measurement
Sensor sub board connector
LSM6DSR SPI mode = 3 (Latch at rise edges)
Motor drivers
Wall sensor PhTrs
Encoders
↑ FRONT
ADCS7476 SPI mode = 3 (Latch at rise edges)

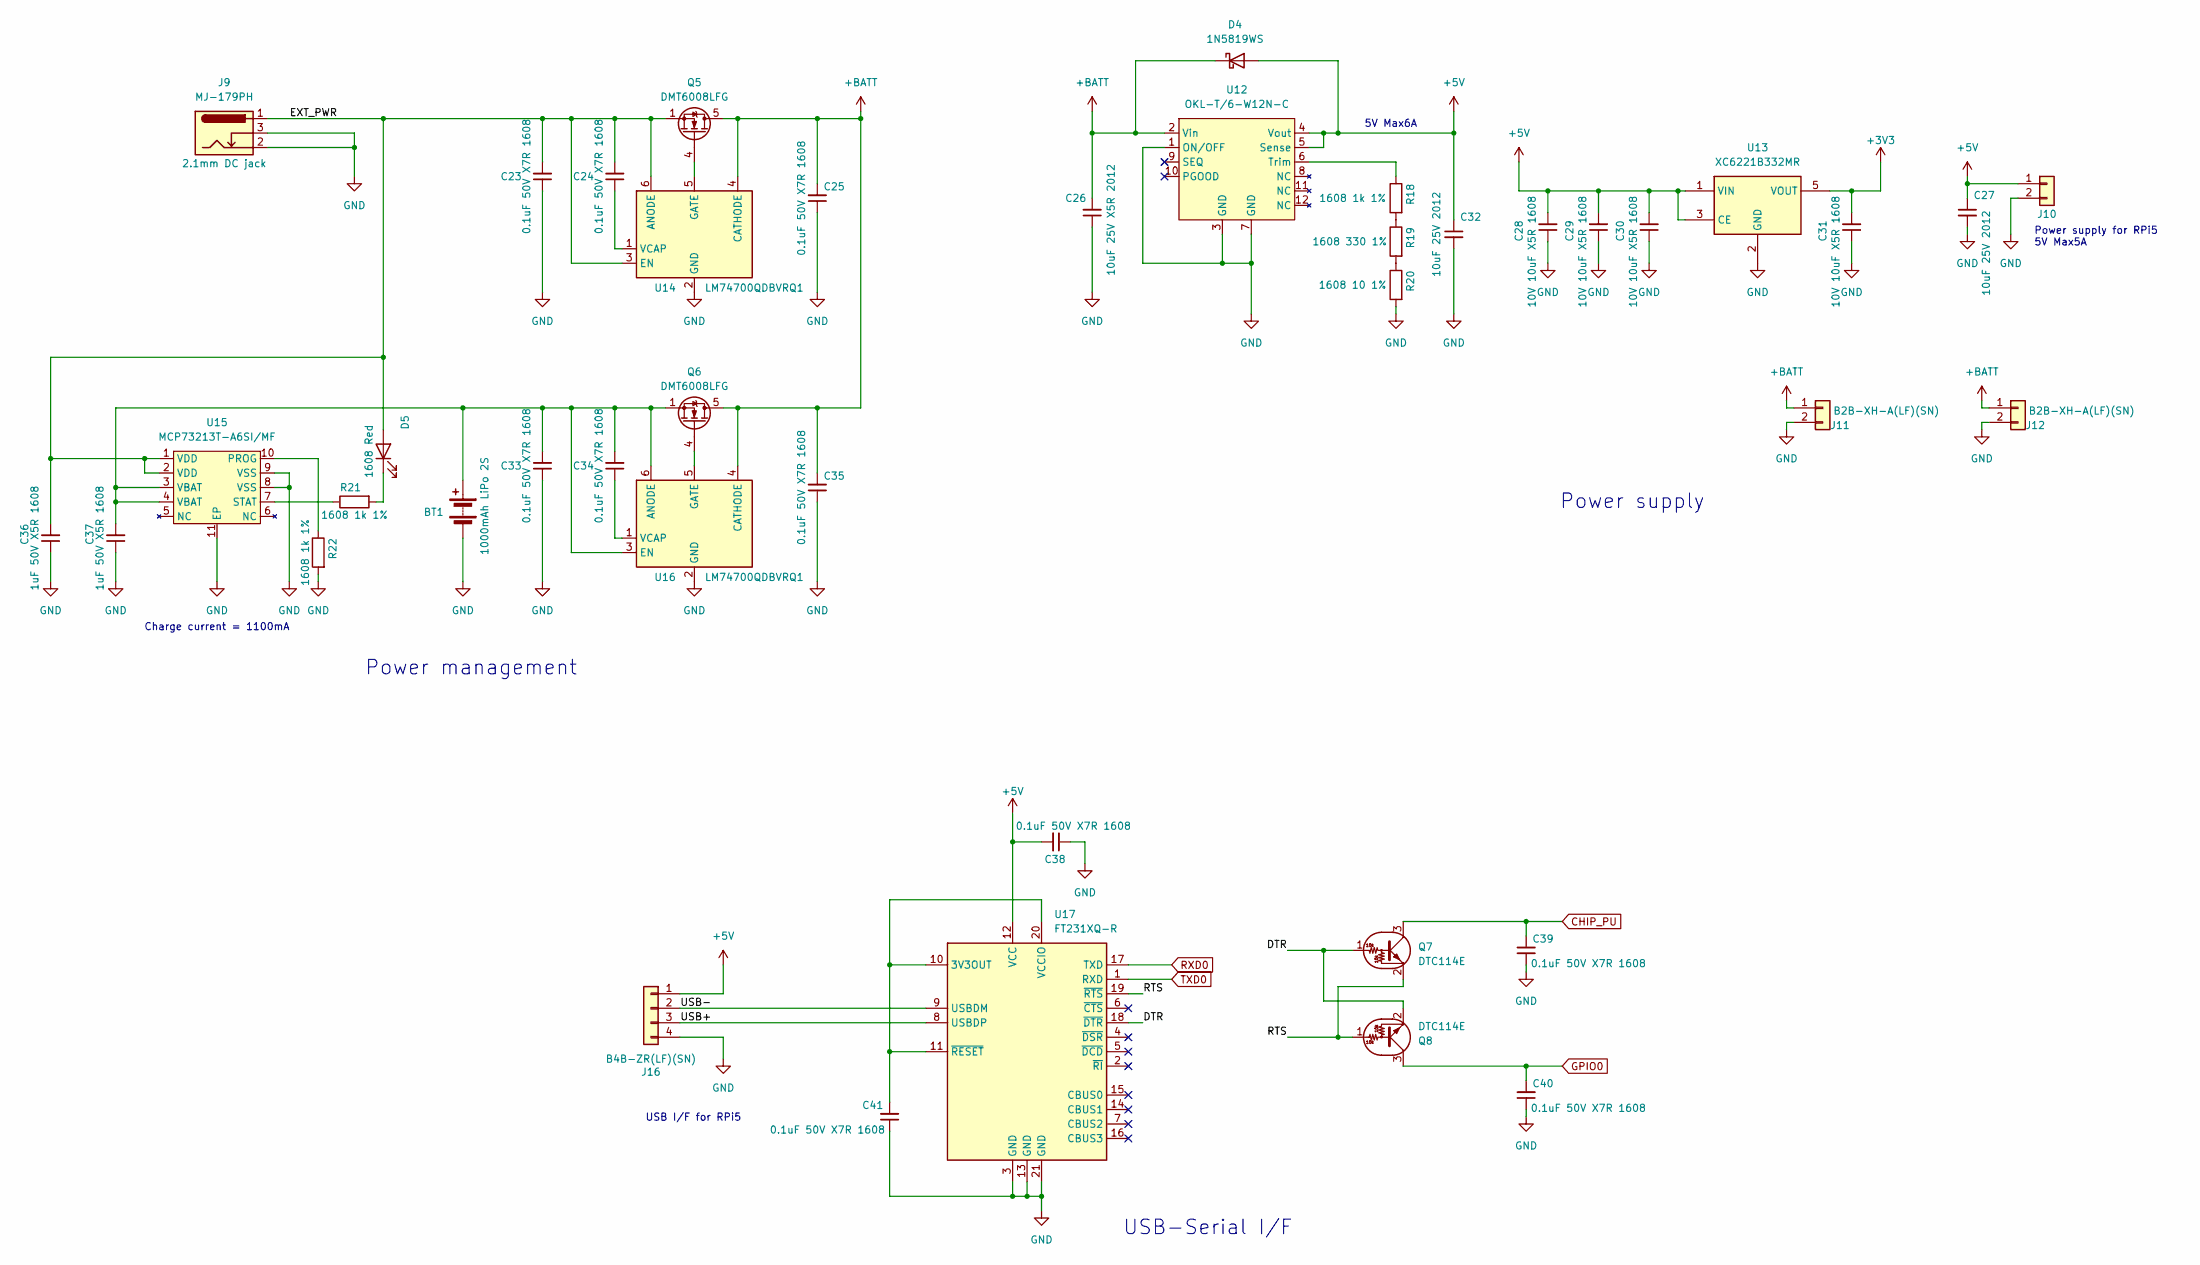
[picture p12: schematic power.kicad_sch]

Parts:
BT1: 1000mAh LiPo 2S; Battery_Connector
C23, C24, C25, C33, C34, C35, C38, C39, C40, C41: CC0603KRX7R9BB104; C_0603_1608Metric
C26, C27, C32: CL21A106KAYNNNE; C_0805_2012Metric
C28, C29, C30, C31: CL10A106KP8NNNC; C_0603_1608Metric
C36, C37: CL10A105KB8NNNC; C_0603_1608Metric
D4: 1N5819WS; D_SOD-323
D5: KT-0603R; LED_0603_1608Metric
J9: MJ-179PH; PJ-002A
J10: Conn_01x02; JST_XH_B2B-XH-AM_1x02_P2.50mm_Vertical
J11, J12: B2B-XH-A(LF)(SN); JST_XH_B2B-XH-AM_1x02_P2.50mm_Vertical
J16: B4B-ZR(LF)(SN); JST_ZH_B4B-ZR_1x04_P1.50mm_Vertical
Q5, Q6: DMT6008LFG; Diodes_PowerDI3333-8
Q7, Q8: DTC114E; SOT-723
R18, R21, R22: 0603WAF1001T5E; R_0603_1608Metric
R19: 0603WAF3300T5E; R_0603_1608Metric
R20: 0603WAF100JT5E; R_0603_1608Metric
U12: OKL-T/6-W12N-C; OKL-T&slash_6-W12N-C_MUR
U13: XC6221B332MR; SOT-23-5
U14, U16: LM74700QDBVRQ1; SOT-23-6
U15: MCP73213T-A6SI/MF; DFN-10-1EP_3x3mm_P0.5mm_EP1.58x2.35mm
U17: FT231XQ-R; QFN-20-1EP_4x4mm_P0.5mm_EP2.5x2.5mm

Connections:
+3V3: C31.2, U13.5 (VOUT); also elsewhere on the board
+5V: C27.1, C28.2, C29.2, C30.2, C32.1, C38.2, D4.2 (A), J10.1, J16.1, U12.4 (Vout), U12.5 (Sense), U13.1 (VIN), U13.3 (CE), U17.12 (VCC); also elsewhere on the board
+BATT: C25.2, C26.2, C35.2, D4.1 (K), J11.1, J12.1, Q5.5 (D), Q6.5 (D), U12.2 (Vin), U14.4 (CATHODE), U16.4 (CATHODE); also elsewhere on the board
/Power/DTR: Q7.1 (B), Q8.2 (E), U17.18 (~DTR)
/Power/EXT_PWR: C23.2, C24.2, C36.2, D5.2 (A), J9.1, Q5.1 (S), Q5.2 (S), Q5.3 (S), U14.3 (EN), U14.6 (ANODE), U15.1 (VDD), U15.2 (VDD)
/Power/RTS: Q7.2 (E), Q8.1 (B), U17.19 (~RTS)
/Power/USB+: J16.3, U17.8 (USBDP)
/Power/USB-: J16.2, U17.9 (USBDM)
CHIP_PU: C39.2, Q7.3 (C); also elsewhere on the board
GND: BT1.2 (-), C23.1, C25.1, C26.1, C27.2, C28.1, C29.1, C30.1, C31.1, C32.2, C33.1, C35.1, C36.1, C37.1, C38.1, C39.1, C40.1, C41.1, J9.2, J9.3, J10.2, J11.2, J12.2, J16.4, R20.2, R22.2, U12.1 (ON/OFF), U12.3 (GND), U12.7 (GND), U13.2 (GND), U14.2 (GND), U15.8 (VSS), U15.9 (VSS), U15.11 (EP), U16.2 (GND), U17.3 (GND), U17.13 (GND), U17.21 (GND); also elsewhere on the board
GPIO0: C40.2, Q8.3 (C); also elsewhere on the board
unnamed: BT1.1 (+), C33.2, C34.2, C37.2, Q6.1 (S), Q6.2 (S), Q6.3 (S), U15.3 (VBAT), U15.4 (VBAT), U16.3 (EN), U16.6 (ANODE)
unnamed: D5.1 (K), R21.2
unnamed: Q5.4 (G), U14.5 (GATE)
unnamed: Q6.4 (G), U16.5 (GATE)
unnamed: R18.2, R19.1
unnamed: R19.2, R20.1
unnamed: R18.1, U12.6 (Trim)
unnamed: C24.1, U14.1 (VCAP)
unnamed: R22.1, U15.10 (PROG)
unnamed: R21.1, U15.7 (STAT)
unnamed: C34.1, U16.1 (VCAP)
unnamed: C41.2, U17.10 (3V3OUT), U17.11 (~RESET), U17.20 (VCCIO)
RXD0: U17.17 (TXD); also elsewhere on the board
TXD0: U17.1 (RXD); also elsewhere on the board

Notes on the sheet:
Charge current = 1100mA
Power supply for RPi5 5V Max5A
5V Max6A
Power management
Power supply
USB I/F for RPi5
USB-Serial I/F

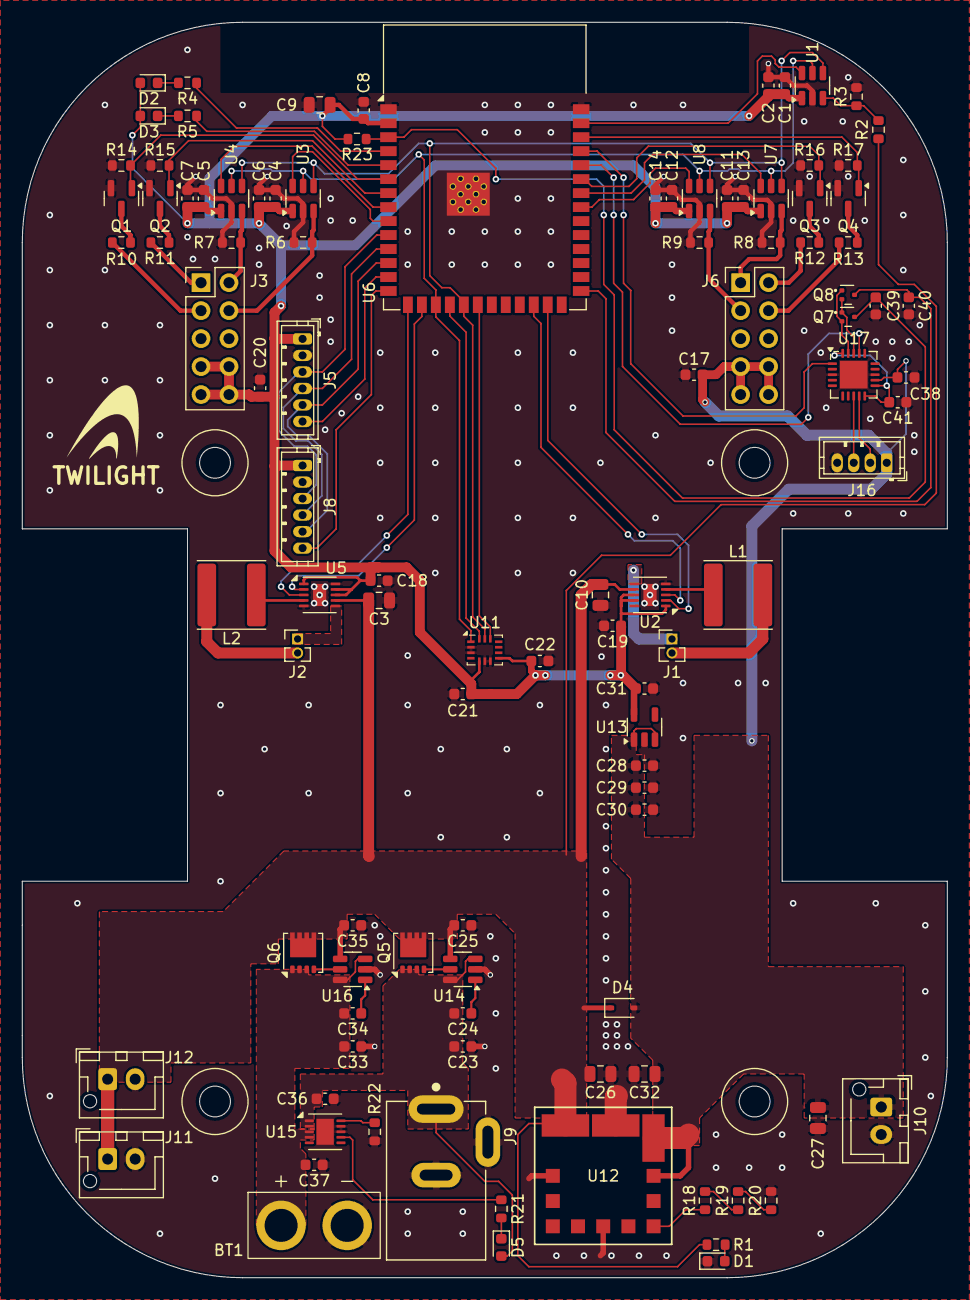
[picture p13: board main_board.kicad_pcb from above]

Board: 2 copper layers, 84.0 x 114.0 mm, 108 parts (0 on the bottom side), 71 nets.

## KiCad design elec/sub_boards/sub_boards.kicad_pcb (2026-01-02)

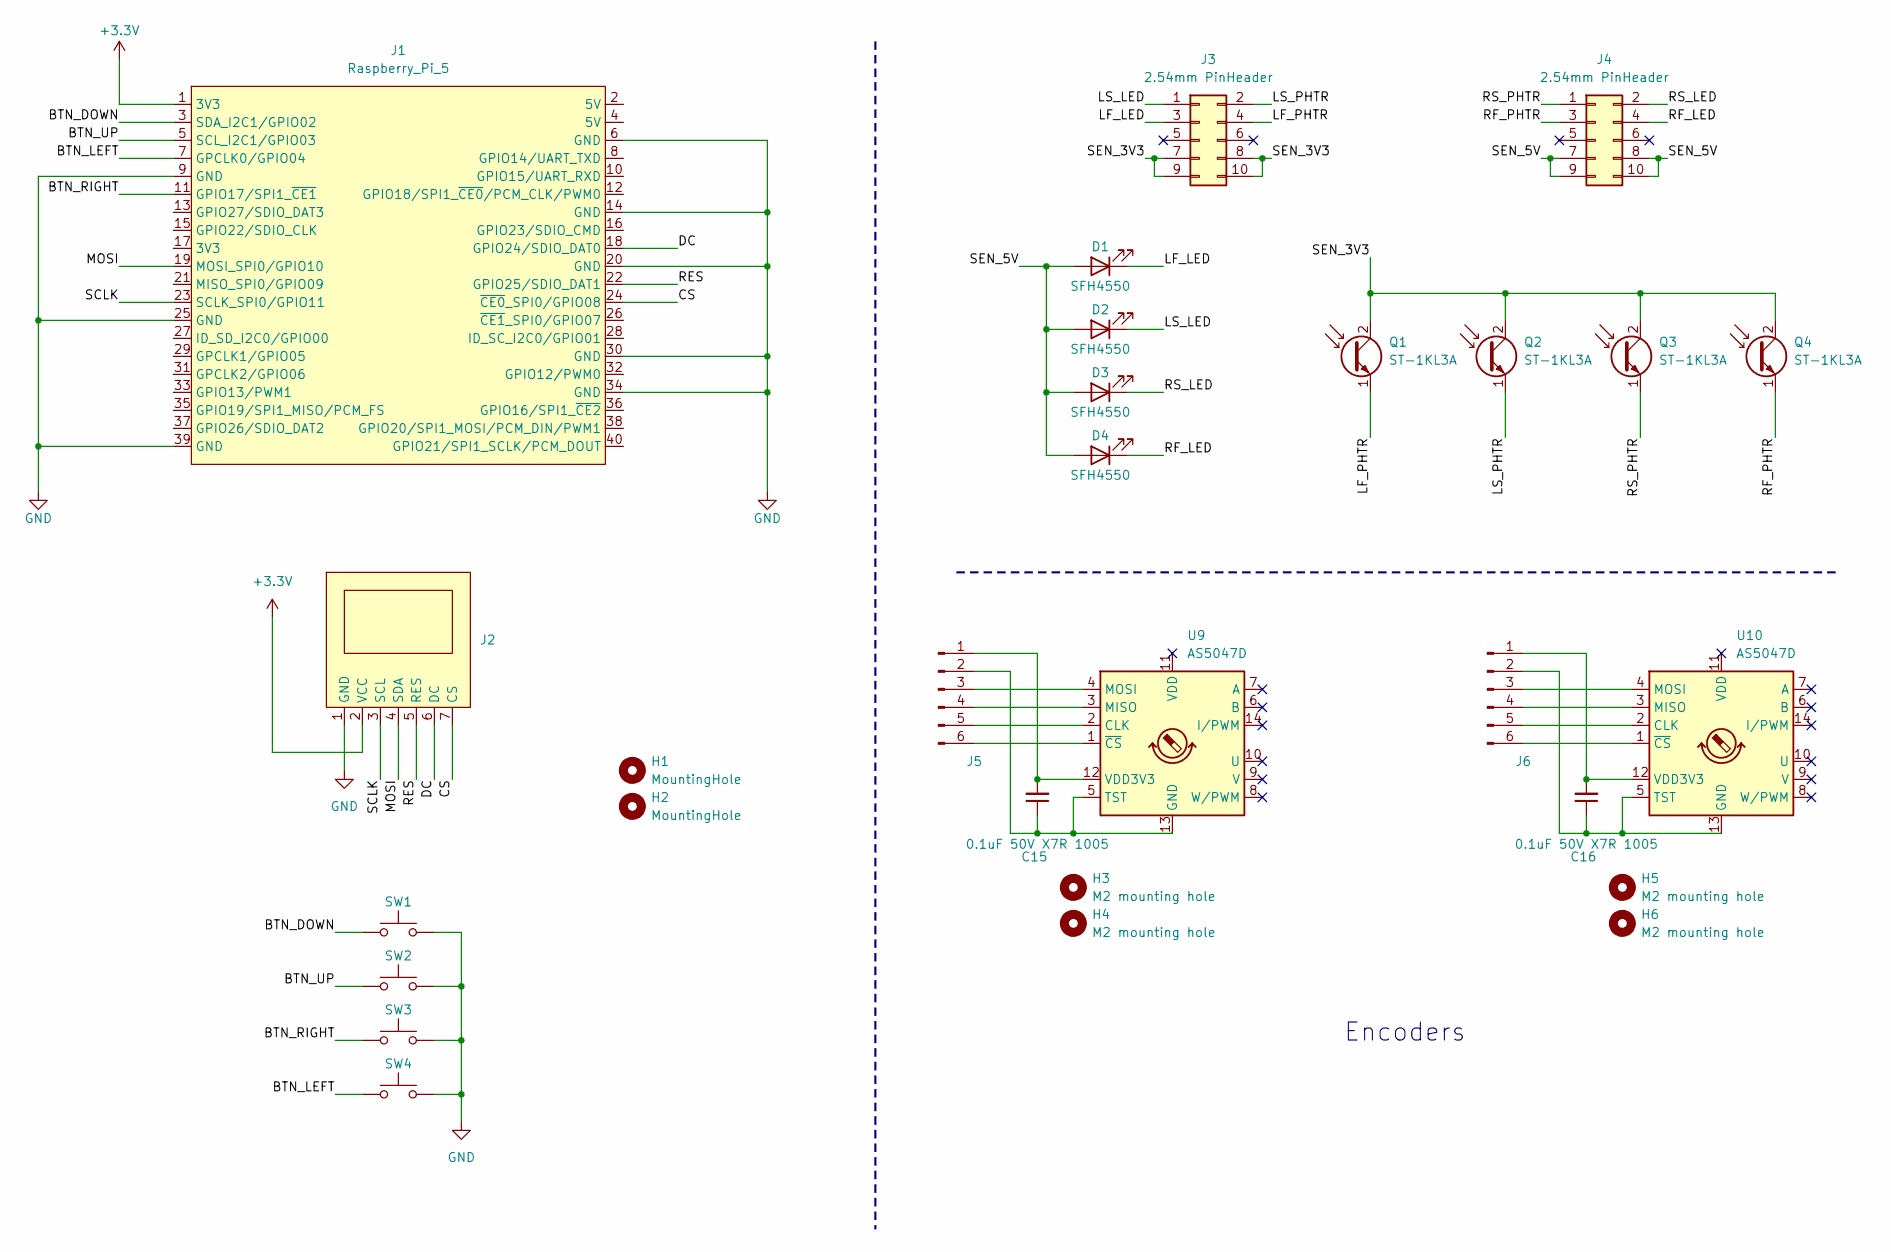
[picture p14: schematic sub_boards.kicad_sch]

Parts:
C15: CC0603KRX7R9BB104; C_0402_1005Metric
C16: CL05B104KO5NNNC; C_0402_1005Metric
D1, D2: SFH4550
D3, D4: SFH4550; SFH4550_Mirror
H1, H2: MountingHole; M2.6 Mounting Hole
H3, H4, H5, H6: M2 mounting hole; MountingHole_2.2mm_M2
J1: Raspberry_Pi_5; PinSocket_2x20_P2.54mm_Vertical
J2: PinSocket_1x07_P2.54mm_Vertical
J3, J4: 2.54mm PinHeader; PinHeader_2x05_P2.54mm_Vertical
J5, J6: EncSide; EncoderPad
Q1, Q2: ST-1KL3A
Q3, Q4: ST-1KL3A; ST-1KL3A_Mirror
SW1, SW2, SW3, SW4: TVBP06-B043CB-B; SW_PUSH_1P1T_6x3.5mm_H4.3_APEM_MJTP1243
U9, U10: AS5047D; TSSOP-14_4.4x5mm_P0.65mm

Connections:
+3.3V: J1.1 (3V3), J2.2 (VCC)
/BTN_DOWN: J1.3 (SDA_I2C1/GPIO02), SW1.1
/BTN_LEFT: J1.7 (GPCLK0/GPIO04), SW4.1
/BTN_RIGHT: J1.11 (GPIO17/SPI1_~CE1), SW3.1
/BTN_UP: J1.5 (SCL_I2C1/GPIO03), SW2.1
/CS: J1.24 (~CE0_SPI0/GPIO08), J2.7 (CS)
/DC: J1.18 (GPIO24/SDIO_DAT0), J2.6 (DC)
/LF_LED: D1.1 (K), J3.3
/LF_PHTR: J3.4, Q1.1 (E)
/LS_LED: D2.1 (K), J3.1
/LS_PHTR: J3.2, Q2.1 (E)
/MOSI: J1.19 (MOSI_SPI0/GPIO10), J2.4 (SDA)
/RES: J1.22 (GPIO25/SDIO_DAT1), J2.5 (RES)
/RF_LED: D4.1 (K), J4.4
/RF_PHTR: J4.3, Q4.1 (E)
/RS_LED: D3.1 (K), J4.2
/RS_PHTR: J4.1, Q3.1 (E)
/SCLK: J1.23 (SCLK_SPI0/GPIO11), J2.3 (SCL)
/SEN_3V3: J3.7, J3.8, J3.9, J3.10, Q1.2 (C), Q2.2 (C), Q3.2 (C), Q4.2 (C)
/SEN_5V: D1.2 (A), D2.2 (A), D3.2 (A), D4.2 (A), J4.7, J4.8, J4.9, J4.10
GND: J1.6 (GND), J1.9 (GND), J1.14 (GND), J1.20 (GND), J1.25 (GND), J1.30 (GND), J1.34 (GND), J1.39 (GND), J2.1 (GND), SW1.2, SW2.2, SW3.2, SW4.2
unnamed: C15.2, J5.1, U9.12 (VDD3V3)
unnamed: C15.1, J5.2, U9.5 (TST), U9.13 (GND)
unnamed: J5.3, U9.4 (MOSI)
unnamed: J5.4, U9.3 (MISO)
unnamed: J5.5, U9.2 (CLK)
unnamed: J5.6, U9.1 (~CS)
unnamed: C16.2, J6.1, U10.12 (VDD3V3)
unnamed: C16.1, J6.2, U10.5 (TST), U10.13 (GND)
unnamed: J6.3, U10.4 (MOSI)
unnamed: J6.4, U10.3 (MISO)
unnamed: J6.5, U10.2 (CLK)
unnamed: J6.6, U10.1 (~CS)

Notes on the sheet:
Encoders

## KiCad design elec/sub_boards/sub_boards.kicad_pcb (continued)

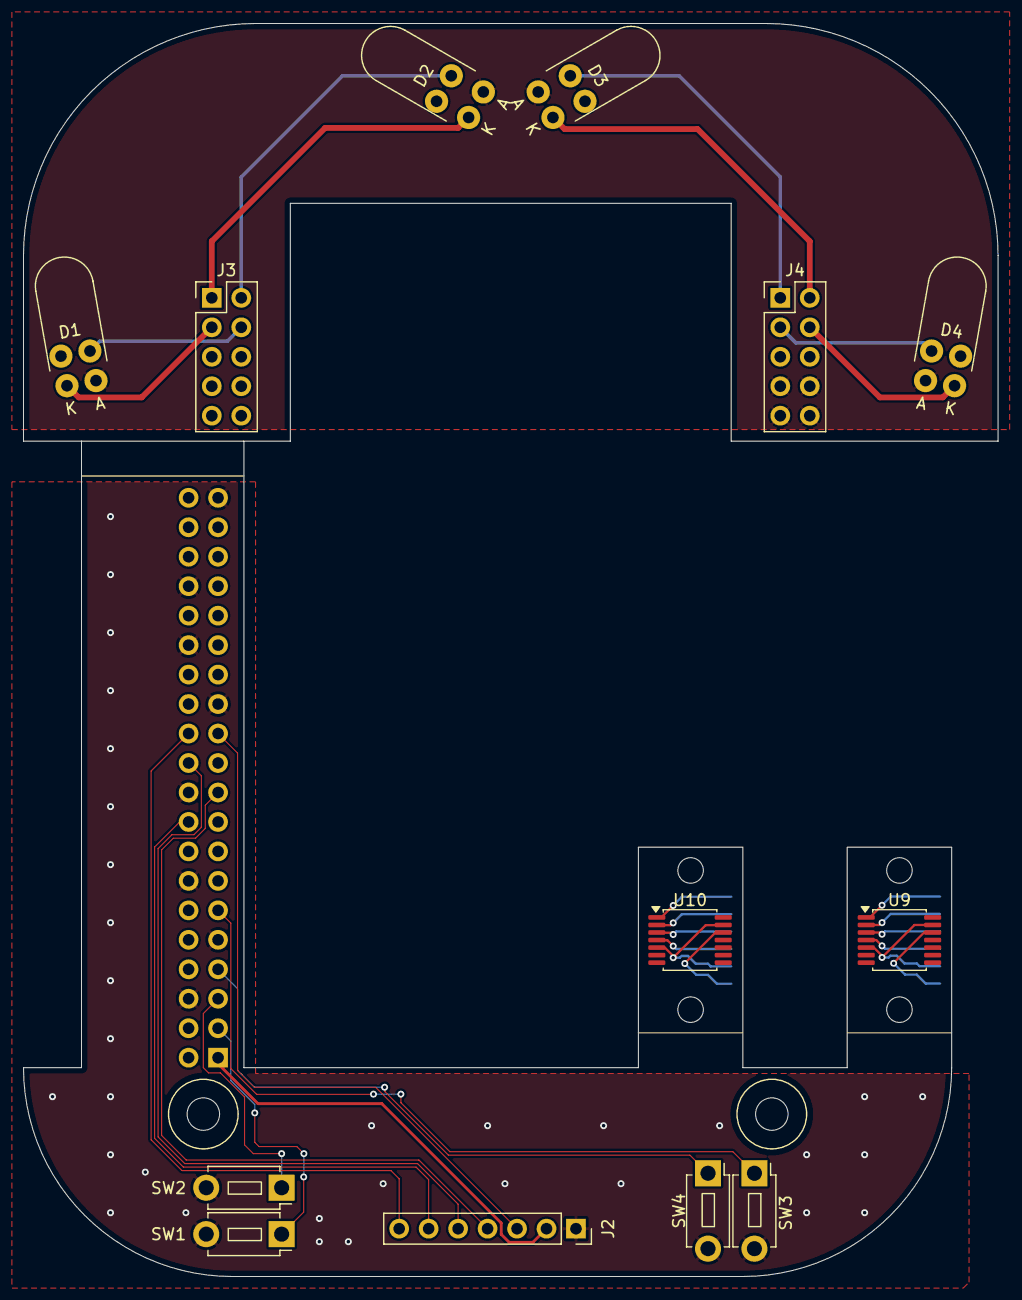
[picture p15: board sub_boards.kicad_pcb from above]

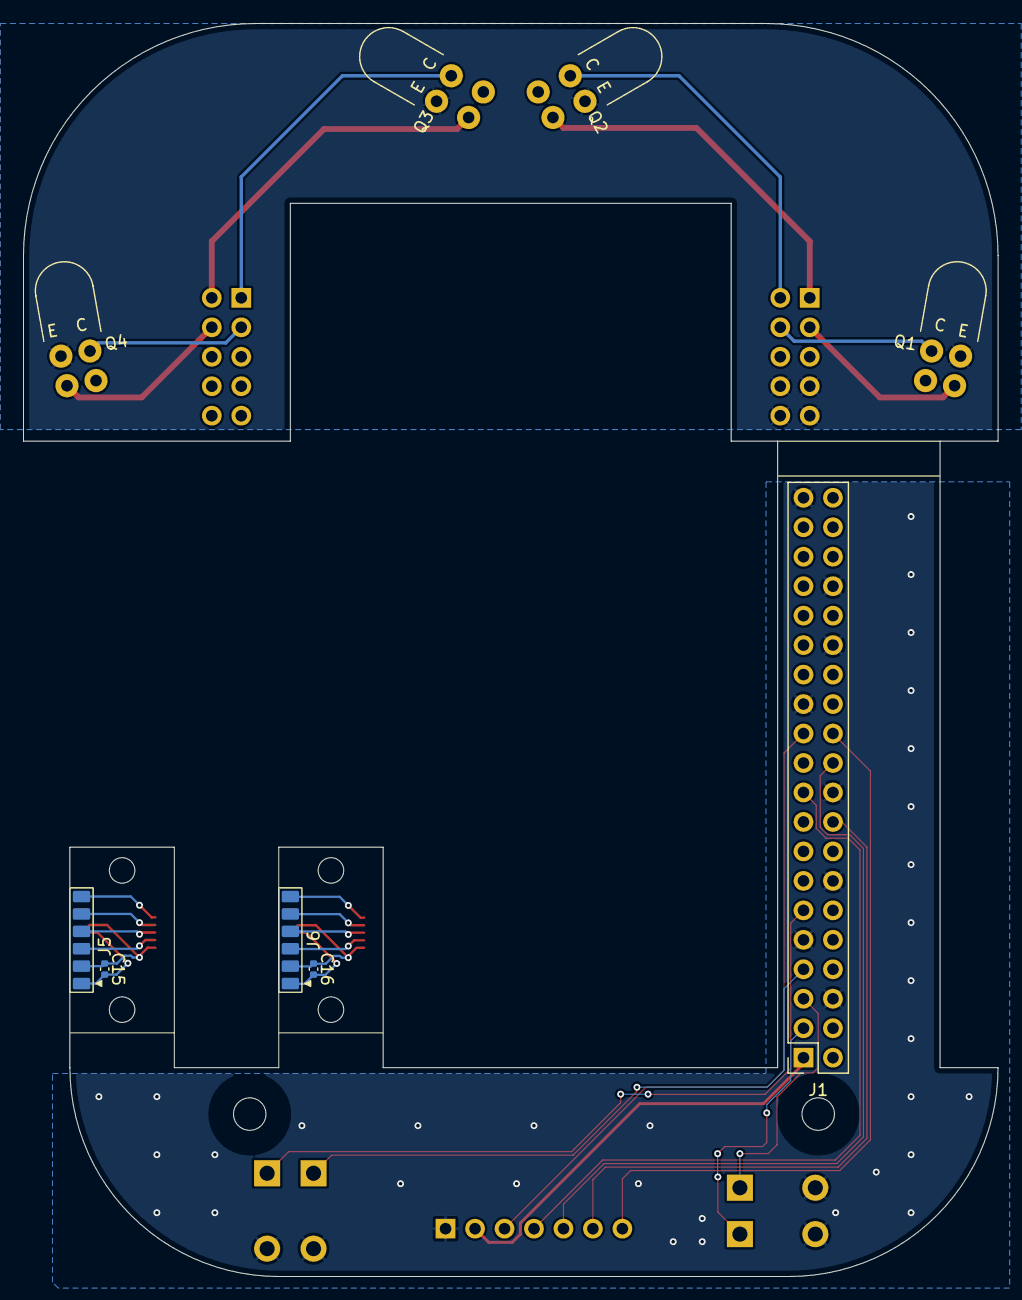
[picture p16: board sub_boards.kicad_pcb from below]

Board: 2 copper layers, 84.0 x 108.0 mm, 28 parts (9 on the bottom side), 33 nets.

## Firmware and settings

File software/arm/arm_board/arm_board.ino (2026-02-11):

/*
 * arm_board.ino - Arduino Nano control board for robotic arm
 * 
 * Pin Configuration:
 * - D8, D9: PWM servo motors
 * - A4, A5: I2C current sensor (INA219)
 * - A1: Battery voltage monitor (10:1 voltage divider)
 * - D11: N-ch MOSFET PWM motor control
 */

#include <Wire.h>
#include <Servo.h>
#include <Adafruit_INA219.h>
#include <Adafruit_NeoPixel.h>

#define LED_SIG (6)
#define NUM_OF_LED (1)

// NeoPixel object
Adafruit_NeoPixel pixels(NUM_OF_LED, LED_SIG, NEO_GRB + NEO_KHZ800);
// Pin definitions
#define SERVO1_PIN 8
#define SERVO2_PIN 9
#define BATTERY_VOLTAGE_PIN A1
#define MOTOR_PWM_PIN 3

// Constants
#define VOLTAGE_DIVIDER_RATIO 11.0  // 10:1 voltage divider
#define ADC_REFERENCE_VOLTAGE 5.0   // Arduino Nano reference voltage
#define ADC_MAX_VALUE 1023.0        // 10-bit ADC
#define DEFAULT_SERVO1_ANGLE 180.0   // Default servo1 position in degrees
#define DEFAULT_SERVO2_ANGLE 180.0  // Default servo2 position in degrees

// Objects
Servo servo1;
Servo servo2;
Adafruit_INA219 ina219;

// Global variables
float batteryVoltage = 0.0;
float current_mA = 0.0;
float busVoltage = 0.0;
float power_mW = 0.0;
bool ina219Available = false;

// Serial communication variables
String inputString = "";
bool stringComplete = false;
unsigned long lastSensorSend = 0;
const unsigned long SENSOR_SEND_INTERVAL = 25;  // 25ms (40Hz)

// Servo control variables
float servo1_current_angle = DEFAULT_SERVO1_ANGLE;
float servo1_target_angle = DEFAULT_SERVO1_ANGLE;
int servo1_speed = 180;  // degrees per second (default: max speed)
float servo2_current_angle = DEFAULT_SERVO2_ANGLE;
float servo2_target_angle = DEFAULT_SERVO2_ANGLE;
int servo2_speed = 180;  // degrees per second (default: max speed)
unsigned long lastServoUpdate = 0;
const unsigned long SERVO_UPDATE_INTERVAL = 5;  // 5ms = 200Hz update rate

void setup() {
  // Initialize serial communication
  Serial.begin(115200);
  Serial.println("Arduino Nano Arm Board Initializing...");
  
  // Initialize servo motors in detached state (no power)
  // Servos will be attached when first command is received
  Serial.println("Servos initialized (detached state)");
  
  // Initialize PWM motor pin
  pinMode(MOTOR_PWM_PIN, OUTPUT);
  
  // Set PWM frequency to 20kHz for motor control
  setupMotorPWM();
  
  analogWrite(MOTOR_PWM_PIN, 0);  // Start with motor off
  Serial.println("Motor PWM pin initialized (20kHz)");
  
  // Initialize battery voltage monitoring pin
  pinMode(BATTERY_VOLTAGE_PIN, INPUT);
  Serial.println("Battery voltage monitor initialized");
  
  // Initialize I2C communication
  Wire.begin();
  Serial.println("I2C initialized");
  
  // Scan for I2C devices
  scanI2CDevices();

  // RGB動作確認
  pixels.begin(); // Initialize the NeoPixel library.
  pixels.setPixelColor(0, pixels.Color(20, 0, 0)); // Blue color
  pixels.show(); // Send the updated pixel colors to the hardware.
  delay(200);
  pixels.setPixelColor(0, pixels.Color(0, 20, 0)); // Green color
  pixels.show(); // Send the updated pixel colors to the hardware.
  delay(200);
  pixels.setPixelColor(0, pixels.Color(0, 0, 20)); // Blue color
  pixels.show(); // Send the updated pixel colors to the hardware.
  delay(200);
  pixels.setPixelColor(0, pixels.Color(20, 20, 20));
  pixels.show();
  delay(200);
  
  // Initialize I2C current sensor
  if (!ina219.begin()) {
    Serial.println("Failed to find INA219 chip - continuing without current sensor");
    ina219Available = false;
  } else {
    Serial.println("INA219 current sensor initialized");
    // Calibration for INA219 (32V, 2A range)
    ina219.setCalibration_32V_2A();
    ina219Available = true;
  }
  
  Serial.println("Setup complete!");
  Serial.println("Commands: S1<angle> S2<angle> M<speed> (e.g., S1090, S2180, M050)");
  inputString.reserve(200);  // Reserve memory for input string
  volatile int dummy;
  for(int i=0; i!=3200; i++) { dummy = i; }
}

void loop() {
  // Handle serial communication
  if (stringComplete) {
    processCommand(inputString);
    inputString = "";
    stringComplete = false;
  }
  
  // Update servo positions with speed control
  if (millis() - lastServoUpdate >= SERVO_UPDATE_INTERVAL) {
    updateServoPositions();
    lastServoUpdate = millis();
  }
  
  // Read sensor values
  readBatteryVoltage();

  readCurrentSensor();
  
  // Send sensor data every 100ms
  if (millis() - lastSensorSend >= SENSOR_SEND_INTERVAL) {
    sendSensorData();
    lastSensorSend = millis();
  }

  if (batteryVoltage > 8.7)
  {
    // AC power connected
    pixels.setPixelColor(0, pixels.Color(0, 0, 20)); // Blue color
    pixels.show(); // Send the updated pixel colors to the hardware.
  }
  else if (batteryVoltage > 6.8)
  {
    // Battery OK
    pixels.setPixelColor(0, pixels.Color(0, 20, 0)); // Green color
    pixels.show(); // Send the updated pixel colors to the hardware.
  }
  else if (batteryVoltage > 6.3)
  {
    // Battery low
    pixels.setPixelColor(0, pixels.Color(20, 20, 0)); // Yellow color
    pixels.show(); // Send the updated pixel colors to the hardware.
  }else
  {
    // Battery critical
    pixels.setPixelColor(0, pixels.Color(20, 0, 0)); // Red color
    pixels.show(); // Send the updated pixel colors to the hardware.
  }
  
  // Small delay for stability (using empty loop instead of delay)
  volatile int dummy;
  for(int i=0; i!=2400; i++) { dummy = i; }  // approximately 1ms with assignment
}

// Utility Functions

/**
 * Serial event handler
 */
void serialEvent() {
  while (Serial.available()) {
    char inChar = (char)Serial.read();
    if (inChar == '\n') {
      stringComplete = true;
    } else {
      inputString += inChar;
    }
  }
}

/**
 * Process incoming commands
 * Commands: S1<angle> S2<angle> M<speed> S1S<speed> S2S<speed> S1A<angle>,<speed> S2A<angle>,<speed> S1D S2D
 * Examples: S1090, S2180, M050, S1S030, S2S060, S1A090,030, S2A045,060, S1D, S2D
 */
void processCommand(String command) {
  command.trim();
  command.toUpperCase();
  
  // デバッグ用: 受信したコマンドを表示
  Serial.println("DEBUG:Received command: '" + command + "'");
  
  if (command.startsWith("S1A")) {
    // S1A<angle>,<speed> - Set servo1 angle with speed
    int commaIndex = command.indexOf(',');
    if (commaIndex > 0) {
      int angle = command.substring(3, commaIndex).toInt();
      int speed = command.substring(commaIndex + 1).toInt();
      setServo1AngleWithSpeed(angle, speed);
      Serial.println("OK:S1A:" + String(angle) + "," + String(speed));
    } else {
      Serial.println("ERROR:S1A_FORMAT");
    }
  }
  else if (command.startsWith("S2A")) {
    // S2A<angle>,<speed> - Set servo2 angle with speed
    int commaIndex = command.indexOf(',');
    if (commaIndex > 0) {
      int angle = command.substring(3, commaIndex).toInt();
      int speed = command.substring(commaIndex + 1).toInt();
      setServo2AngleWithSpeed(angle, speed);
      Serial.println("OK:S2A:" + String(angle) + "," + String(speed));
    } else {
      Serial.println("ERROR:S2A_FORMAT");
    }
  }
  else if (command.startsWith("S1S")) {
    // S1S<speed> - Set servo1 default speed
    int speed = command.substring(3).toInt();
    setServo1Speed(speed);
    Serial.println("OK:S1S:" + String(speed));
  }
  else if (command.startsWith("S2S")) {
    // S2S<speed> - Set servo2 default speed
    int speed = command.substring(3).toInt();
    setServo2Speed(speed);
    Serial.println("OK:S2S:" + String(speed));
  }
  else if (command == "S1D") {
    // S1D - Detach servo1 (power off)
    servo1.detach();
    Serial.println("OK:S1D");
  }
  else if (command == "S2D") {
    // S2D - Detach servo2 (power off)
    servo2.detach();
    Serial.println("OK:S2D");
  }
  else if (command.startsWith("S1")) {
    int angle = command.substring(2).toInt();
    setServo1Angle(angle);
    Serial.println("OK:S1:" + String(angle));
  }
  else if (command.startsWith("S2")) {
    int angle = command.substring(2).toInt();
    setServo2Angle(angle);
    Serial.println("OK:S2:" + String(angle));
  }
  else if (command.startsWith("M")) {
    int speed = command.substring(1).toInt();
    setMotorSpeedPercent(speed);
    Serial.println("OK:M:" + String(speed));
  }
  else if (command == "STATUS") {
    sendSensorData();
  }
  else if (command == "STOP") {
    emergencyStop();
    Serial.println("OK:STOP");
  }
  else {
    Serial.println("ERROR:UNKNOWN_COMMAND:" + command);
  }
}

/**
 * Send sensor data in structured format
 * Format: DATA:<battery_voltage>,<current_mA>,<power_mW>
 */
void sendSensorData() {
  Serial.print("DATA:");
  Serial.print(batteryVoltage, 2);
  Serial.print(",");
  Serial.print(current_mA, 1);
  Serial.print(",");
  Serial.println(power_mW, 1);
}

/**
 * Read battery voltage through voltage divider
 */
void readBatteryVoltage() {
  int adcValue = analogRead(BATTERY_VOLTAGE_PIN);
  batteryVoltage = (adcValue * ADC_REFERENCE_VOLTAGE / ADC_MAX_VALUE) * VOLTAGE_DIVIDER_RATIO;
}

/**
 * Read current sensor values
 */
void readCurrentSensor() {
  if (ina219Available) {
    busVoltage = ina219.getBusVoltage_V();
    current_mA = ina219.getCurrent_mA();
    power_mW = ina219.getPower_mW();
  } else {
    busVoltage = 0.0;
    current_mA = 0.0;
    power_mW = 0.0;
  }
}

/**
 * Print all sensor values to serial (for debugging)
 */
void printSensorValues() {
  Serial.println("DEBUG:=== Sensor Readings ===");
  Serial.print("DEBUG:Battery Voltage: ");
  Serial.print(batteryVoltage, 2);
  Serial.println(" V");
  
  if (ina219Available) {
    Serial.print("DEBUG:Bus Voltage: ");
    Serial.print(busVoltage, 2);
    Serial.println(" V");
    
    Serial.print("DEBUG:Current: ");
    Serial.print(current_mA, 1);
    Serial.println(" mA");
    
    Serial.print("DEBUG:Power: ");
    Serial.print(power_mW, 1);
    Serial.println(" mW");
  } else {
    Serial.println("DEBUG:INA219 not available - no current/power data");
  }
  
  Serial.println("DEBUG:========================");
}

/**
 * Update servo positions with speed control
 */
void updateServoPositions() {
  // Update servo1 position
  if (servo1_current_angle != servo1_target_angle) {
    float step_size = (float)servo1_speed * SERVO_UPDATE_INTERVAL / 1000.0;  // degrees per update
    
    if (abs(servo1_target_angle - servo1_current_angle) <= step_size) {
      servo1_current_angle = servo1_target_angle;
    } else if (servo1_target_angle > servo1_current_angle) {
      servo1_current_angle += step_size;
    } else {
      servo1_current_angle -= step_size;
    }
    
    servo1.write((int)servo1_current_angle);
  }
  
  // Update servo2 position
  if (servo2_current_angle != servo2_target_angle) {
    float step_size = (float)servo2_speed * SERVO_UPDATE_INTERVAL / 1000.0;  // degrees per update
    
    if (abs(servo2_target_angle - servo2_current_angle) <= step_size) {
      servo2_current_angle = servo2_target_angle;
    } else if (servo2_target_angle > servo2_current_angle) {
      servo2_current_angle += step_size;
    } else {
      servo2_current_angle -= step_size;
    }
    
    servo2.write((int)servo2_current_angle);
  }
}

/**
 * Control servo motor 1 (immediate)
 * @param angle: angle in degrees (0-180)
 */
void setServo1Angle(int angle) {
  angle = constrain(angle, 0, 180);
  servo1_current_angle = (float)angle;
  servo1_target_angle = (float)angle;
  if (!servo1.attached()) {
    servo1.attach(SERVO1_PIN);
  }
  servo1.write(angle);
}

/**
 * Control servo motor 2 (immediate)
 * @param angle: angle in degrees (0-180)
 */
void setServo2Angle(int angle) {
  angle = constrain(angle, 0, 180);
  servo2_current_angle = (float)angle;
  servo2_target_angle = (float)angle;
  if (!servo2.attached()) {
    servo2.attach(SERVO2_PIN);
  }
  servo2.write(angle);
}

/**
 * Control servo motor 1 with speed
 * @param angle: target angle in degrees (0-180)
 * @param speed: speed in degrees per second (1-180)
 */
void setServo1AngleWithSpeed(int angle, int speed) {
  angle = constrain(angle, 0, 180);
  speed = constrain(speed, 1, 180);
  servo1_target_angle = (float)angle;
  servo1_speed = speed;
  
  // デバッグ情報を追加
  Serial.print("DEBUG:S1 current=");
  Serial.print(servo1_current_angle);
  Serial.print(" target=");
  Serial.print(servo1_target_angle);
  Serial.print(" speed=");
  Serial.println(servo1_speed);
}

/**
 * Control servo motor 2 with speed
 * @param angle: target angle in degrees (0-180)
 * @param speed: speed in degrees per second (1-180)
 */
void setServo2AngleWithSpeed(int angle, int speed) {
  angle = constrain(angle, 0, 180);
  speed = constrain(speed, 1, 180);
  servo2_target_angle = (float)angle;
  servo2_speed = speed;
  
  // デバッグ情報を追加
  Serial.print("DEBUG:S2 current=");
  Serial.print(servo2_current_angle);
  Serial.print(" target=");
  Serial.print(servo2_target_angle);
  Serial.print(" speed=");
  Serial.println(servo2_speed);
}

/**
 * Set servo1 default speed
 * @param speed: speed in degrees per second (1-180)
 */
void setServo1Speed(int speed) {
  speed = constrain(speed, 1, 180);
  servo1_speed = speed;
}

/**
 * Set servo2 default speed
 * @param speed: speed in degrees per second (1-180)
 */
void setServo2Speed(int speed) {
  speed = constrain(speed, 1, 180);
  servo2_speed = speed;
}

/**
 * Control motor speed via PWM (0-255)
 * @param speed: speed value (0-255)
 */
void setMotorSpeed(int speed) {
  speed = constrain(speed, 0, 255);
  analogWrite(MOTOR_PWM_PIN, speed);
}

/**
 * Setup PWM frequency for motor control (20kHz)
 */
void setupMotorPWM() {
  // Timer2 settings for 20kHz PWM frequency
  // Phase Correct PWM mode, non-inverting, prescaler = 1
  // D3 is connected to OC2B (Timer2 Channel B)
  TCCR2A = _BV(COM2B1) | _BV(WGM20);  // Phase Correct PWM mode, OC2B output
  TCCR2B = _BV(CS20);                  // Prescaler = 1
  // Frequency = 16MHz / (2 * 1 * 256) = 31.25kHz (closest achievable)
  // Note: Exact 20kHz not possible with Timer2 on 16MHz Arduino
  // Using prescaler=1 gives ~31kHz, prescaler=8 gives ~4kHz
}

/**
 * Control motor speed in percentage (0-100%)
 * @param percent: speed percentage (0-100)
 */
void setMotorSpeedPercent(int percent) {
  percent = constrain(percent, 0, 100);
  int pwmValue = map(percent, 0, 100, 0, 255);
  analogWrite(MOTOR_PWM_PIN, pwmValue);
}

/**
 * Get battery voltage
 * @return: battery voltage in volts
 */
float getBatteryVoltage() {
  return batteryVoltage;
}

/**
 * Get current consumption
 * @return: current in mA
 */
float getCurrentmA() {
  return current_mA;
}

/**
 * Get power consumption
 * @return: power in mW
 */
float getPowermW() {
  return power_mW;
}

/**
 * Scan for I2C devices
 */
void scanI2CDevices() {
  Serial.println("Scanning for I2C devices...");
  int deviceCount = 0;
  
  for (byte address = 1; address < 127; address++) {
    Wire.beginTransmission(address);
    if (Wire.endTransmission() == 0) {
      Serial.print("I2C device found at address 0x");
      if (address < 16) Serial.print("0");
      Serial.print(address, HEX);
      Serial.println(" !");
      deviceCount++;
    }
  }
  
  if (deviceCount == 0) {
    Serial.println("No I2C devices found");
  } else {
    Serial.print(deviceCount);
    Serial.println(" I2C device(s) found");
  }
  Serial.println();
}

/**
 * Emergency stop - stop all motors and servos
 */
void emergencyStop() {
  servo1.write(DEFAULT_SERVO1_ANGLE);  // Default position
  servo2.write(DEFAULT_SERVO2_ANGLE);  // Default position
  analogWrite(MOTOR_PWM_PIN, 0);  // Stop motor
  Serial.println("EMERGENCY STOP ACTIVATED");
}

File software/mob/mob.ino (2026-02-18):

#include <SPI.h>
#include <WiFi.h>
#include <atomic>
#include <esp_task_wdt.h>  // 追加
#include "spi_manager.h"
#include "adc.h"
#include "led.h"
#include "wall_sensor.h"
#include "imu.h"
#include "motor.h"
#include "encoder.h"
#include "sensors.h"
#include "motion_controller.h"
#include <math.h>

// Target wheel speed [m/s] (updated from MOT command via cmd_queue)
static float target_vr_mps = 0.0f;
static float target_vl_mps = 0.0f;

// 前進コマンド（プロファイル走行）状態
static bool fwd_active = false;
static float fwd_v_cmd_mmps = 0.0f;     // 現在指令速度 [mm/s]
static float fwd_v_target_mmps = 0.0f;  // 目標巡航速度 [mm/s]
static float fwd_a_mmps2 = 0.0f;        // 加速度 [mm/s^2]（符号付き）
static float fwd_goal_dist_mm = 0.0f;   // 絶対目標距離 [mm]（Sensors::get_distance()基準）
static float fwd_target_angle_rad = 0.0f; // 目標角度 [rad] （角度フィードバック用）
static float cumulative_goal_dist_mm = 0.0f; // 累積目標距離 [mm]（RDSTでリセット）

// 停止コマンド（減速して停止する）状態
static bool stop_active = false;
static float stop_v_cmd_mmps = 0.0f;      // 現在指令速度 [mm/s]
static float stop_a_mmps2 = 0.0f;         // 減速度 [mm/s^2]（負ではなく絶対値として扱う）
static float stop_goal_dist_mm = 0.0f;    // 絶対目標距離 [mm]
static float stop_target_angle_rad = 0.0f; // 目標角度 [rad] （角度フィードバック用）
static float stop_cruise_mmps = 0.0f;     // STOP引数speed_mmps（巡航速度想定）[mm/s]
static float stop_elapsed_s = 0.0f;       // STOP経過時間 [s]
static bool stop_backoff_active = false;  // タイムアウト後の後退中か
static float stop_backoff_target_dist_mm = 0.0f; // 後退完了目標距離 [mm]

static constexpr float FINAL_APPROACH_SPEED_MMPS = 50.0f;  // STOP時の最終進入速度
static constexpr float STOP_MIN_SPEED_MMPS = 20.0f;        // STOP時の最低速度 [mm/s]
static constexpr float STOP_TIMEOUT_SEC = 4.0f;            // STOPのタイムアウト [s]
static constexpr float STOP_BACKOFF_DIST_MM = 30.0f;       // タイムアウト時の後退距離 [mm]
static constexpr float STOP_BACKOFF_SPEED_MPS = 0.12f;     // タイムアウト時の後退速度 [m/s]

// 旋回コマンド（その場旋回）状態
static bool turn_active = false;
static float turn_goal_angle_rad = 0.0f;
static float turn_speed_cmd_mps = 0.0f; // 指令速度（加減速制限後）

// 低速動作コマンド（L*）状態
enum class LatchMode : uint8_t {
    NONE = 0,
    FWD,
    BACK,
    TURN_L,
    TURN_R,
};

static bool latch_active = false;
static LatchMode latch_mode = LatchMode::NONE;
static float latch_turn_target_rad = 0.0f;

static constexpr float LATCH_SPEED_MPS = 0.05f;        // 50mm/s（Lowspeed）
static constexpr float LATCH_TURN_SPEED_MPS = 0.06f;   // 約90deg/s相当（Lowspeed）
static constexpr float LATCH_TURN_TARGET_RAD = 1000000.0f; // 低速連続旋回の仮想目標角

// JOGコマンド（距離指定低速動作）状態
static bool jog_active = false;
static bool jog_is_forward = true;  // true: 前進, false: 後退
static float jog_target_dist_mm = 0.0f;
static float jog_start_dist_mm = 0.0f;
static constexpr float JOG_SPEED_MPS = 0.05f;  // 50mm/s

// ジャイロキャリブレーション状態
static bool gyro_calib_done_pending = false;  // キャリブレーション完了時にDONEを返す

// QSTPコマンド（クイック停止）状態
static bool qstp_active = false;
static float qstp_v_cmd_mmps = 0.0f;      // 現在指令速度 [mm/s]
static float qstp_target_angle_rad = 0.0f; // 目標角度 [rad] （角度フィードバック用）
static float qstp_original_goal_dist_mm = 0.0f; // 元の目標距離 [mm]（FWD/STOPの目標）
static constexpr float QSTP_DECEL_MMPS2 = 1000.0f;  // QSTP時の最大減速度 [mm/s^2]

// 角度制御パラメータ（簡易P + 速度制限）
static constexpr float TURN_KP_MPS_PER_RAD = 0.35f;   // [m/s]/rad
static constexpr float TURN_MAX_SPEED_MPS = 0.25f;
static constexpr float TURN_MIN_SPEED_MPS = 0.04f;
static constexpr float TURN_DONE_TOL_RAD = 0.03f;     // 約1.7deg
static constexpr float TURN_ACCEL_MPS2 = 1.2f;        // 旋回時の車輪速度加速度制限 [m/s^2]

// 直進時の角度フィードバックゲイン
static constexpr float ANGLE_FB_GAIN = 0.3f;  // [m/s]/rad

// 直進時の角速度フィードバックゲイン（角速度→0）
static constexpr float ANGULAR_RATE_FB_GAIN = 0.01f;  // [m/s]/(rad/s)

// 壁センサフィードバックパラメータ
static constexpr float WALL_SENSOR_THRESHOLD = 100.0f;  // 壁検出閾値
// １号機
//static constexpr float WALL_SENSOR_TARGET_LS = 250.0f;     // 中央時の目標値
//static constexpr float WALL_SENSOR_TARGET_RS = 234.0f;     // 中央時の目標値
// ２号機
static constexpr float WALL_SENSOR_TARGET_LS = 233.0f;     // 中央時の目標値
static constexpr float WALL_SENSOR_TARGET_RS = 209.0f;     // 中央時の目標値

static constexpr float WALL_SENSOR_GAIN = 0.000005f;      // 壁センサフィードバックゲイン [m/s] per sensor unit
static constexpr float WALL_CORRECTION_CUT_OFF_DISTANCE = 30.0f; // 壁センサ補正を行う残距離の閾値 [mm]

// 壁センサを使用した横方向補正値を計算
// 戻り値: 正の値は右に寄せる補正、負の値は左に寄せる補正
static float calculate_wall_correction(const Sensors& sensors_ref) {
    const uint16_t rs_val = sensors_ref.get_rs();  // 右側センサ
    const uint16_t ls_val = sensors_ref.get_ls();  // 左側センサ
    
    const bool rs_valid = (rs_val >= WALL_SENSOR_THRESHOLD);
    const bool ls_valid = (ls_val >= WALL_SENSOR_THRESHOLD);
    
    float correction = 0.0f;
    
    if (rs_valid && ls_valid) {
        // 両方のセンサが有効な場合：両方を使用
        const float rs_error = WALL_SENSOR_TARGET_RS - static_cast<float>(rs_val);
        const float ls_error = static_cast<float>(ls_val) - WALL_SENSOR_TARGET_LS;
        correction = (rs_error + ls_error) * 0.5f * WALL_SENSOR_GAIN;
    } else if (ls_valid) {
        // 左センサのみ有効：左センサを使用して右に寄せる
        const float ls_error = static_cast<float>(ls_val) - WALL_SENSOR_TARGET_LS;
        correction = ls_error * WALL_SENSOR_GAIN;
    } else if (rs_valid) {
        // 右センサのみ有効：右センサを使用して左に寄せる
        const float rs_error = WALL_SENSOR_TARGET_RS - static_cast<float>(rs_val);
        correction = rs_error * WALL_SENSOR_GAIN;
    }
    // 両方無効な場合は correction = 0.0f のまま
    
    return correction;
}

static inline float slew_rate_limit(float current, float target, float max_delta) {
    if (target > current + max_delta) return current + max_delta;
    if (target < current - max_delta) return current - max_delta;
    return target;
}

// グローバルなクラスは、上から順に初期化される
ADC adc(get_shared_spi());
LED led;
WallSensor wall_sensor(adc);
IMU imu(get_shared_spi());
Motor motor;
Encoder encoder;
Sensors sensors(imu, wall_sensor, adc, encoder);
MotionController motion(motor, sensors);

hw_timer_t* high_speed_timer = NULL;
std::atomic<uint32_t> timer_ticks(0);

QueueHandle_t cmd_queue; // コマンドキュー
QueueHandle_t msg_queue; // Core0 -> Core1 メッセージキュー（Serial出力用）

// ---- Core1(loop) -> Core0(RealtimeTask) コマンド定義 ----
struct SetMotorSpeedCommand {
    int16_t right_speed; // mm/s（互換）
    int16_t left_speed;  // mm/s（互換）
};

struct ForwardCommand {
    float speed_mmps;
    float accel_mmps2;
    float distance_mm;
};

struct StopCommand {
    float speed_mmps;
    float accel_mmps2;
    float distance_mm;
};

struct LatchCommand {
    uint8_t mode; // LatchMode
};

struct JogCommand {
    bool is_forward;  // true: 前進, false: 後退
    float distance_mm;
};

enum CommandID : uint8_t {
    CMD_SET_MOTOR_SPEED = 0x01,
    CMD_FORWARD = 0x04,
    CMD_STOP = 0x05,
    CMD_RESET_DISTANCE = 0x06,
    CMD_RESET_ANGLE = 0x07,
    CMD_TURN = 0x08,
    CMD_GYRO_CALIBRATE = 0x09,
    CMD_LATCH_START = 0x0A,
    CMD_LATCH_STOP = 0x0B,
    CMD_JOG_START = 0x0C,
    CMD_QSTP = 0x0D,
};
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

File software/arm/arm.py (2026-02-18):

#!/usr/bin/env python3
"""
arm.py - 統合アームコントローラー

Futabaサーボ(RS204MD/RS304MD)とArduino Nanoを統合した単一クラス。
- servo_arm: Futabaコマンドサーボ（投擲アーム用）
- servo_launcher: Arduino制御サーボ（ランチャー用）
- motor: Arduino制御DCモータ
- sensor: Arduino経由のセンサーデータ
"""

import serial
import threading
import time
import queue
from abc import ABC, abstractmethod
from dataclasses import dataclass
from typing import Optional, Callable


@dataclass
class SensorData:
    """センサーデータクラス"""
    battery_voltage: float  # バッテリー電圧 [V]
    current_mA: float      # 電流 [mA]
    power_mW: float        # 消費電力 [mW]
    timestamp: float       # タイムスタンプ


class ArmBase(ABC):
    """アームコントローラーの抽象基底クラス"""
    
    # アーム角度定数
    CATCH_POSITION = None    # ボールキャッチ位置
    THROW_POSITION = -45.0   # 投擲位置
    RUN_POSITION = None     # 走行位置
    
    # ランチャーサーボ角度定数
    LAUNCHER_RELOAD = 180    # リロード位置
    LAUNCHER_READY = 30      # 待機位置
    LAUNCHER_FIRE = 0        # 発射位置
    
    @abstractmethod
    def connect_arduino(self) -> bool:
        """Arduinoに接続"""
        pass
    
    @abstractmethod
    def disconnect(self):
        """すべての接続を切断"""
        pass
    
    @abstractmethod
    def set_servo_arm_torque(self, enable: bool):
        """アームサーボのトルクON/OFF"""
        pass
    
    @abstractmethod
    def set_servo_arm_angle(self, angle: float, move_time: int = 0):
        """アームサーボの目標角度設定"""
        pass
    
    @abstractmethod
    def set_servo_arm_brake(self):
        """アームサーボをブレーキモードに設定"""
        pass
    
    @abstractmethod
    def set_servo_launcher_angle(self, angle: int) -> bool:
        """ランチャーサーボの角度を設定"""
        pass
    
    @abstractmethod
    def set_servo_launcher_angle_with_speed(self, angle: int, speed: int) -> bool:
        """ランチャーサーボの角度を指定速度で設定"""
        pass
    
    @abstractmethod
    def set_servo_launcher_speed(self, speed: int) -> bool:
        """ランチャーサーボのデフォルト速度を設定"""
        pass
    
    @abstractmethod
    def detach_servo_launcher(self) -> bool:
        """ランチャーサーボを脱力状態にする"""
        pass
    
    @abstractmethod
    def set_motor_speed(self, speed: int) -> bool:
        """モータ速度を設定"""
        pass
    
    @abstractmethod
    def emergency_stop(self) -> bool:
        """緊急停止"""
        pass
    
    @abstractmethod
    def request_status(self) -> bool:
        """ステータス要求"""
        pass
    
    @abstractmethod
    def get_latest_sensor_data(self) -> Optional[SensorData]:
        """最新のセンサーデータを取得"""
        pass
    
    @abstractmethod
    def get_sensor_data_queue(self) -> queue.Queue:
        """センサーデータキューを取得"""
        pass
    
    @abstractmethod
    def set_sensor_callback(self, callback: Callable[[SensorData], None]):
        """センサーデータ受信時のコールバック関数を設定"""
        pass
    
    @abstractmethod
    def __enter__(self):
        """コンテキストマネージャー対応"""
        pass
    
    @abstractmethod
    def __exit__(self, exc_type, exc_val, exc_tb):
        """コンテキストマネージャー対応"""
        pass


class Arm(ArmBase):
    """統合アームコントローラークラス"""
    
    # Futabaサーボのメモリマップアドレス
    ADDR_TORQUE_ENABLE = 0x24
    ADDR_GOAL_POSITION = 0x1E
    ADDR_GOAL_TIME = 0x20
    
    # アーム角度定数
    CATCH_POSITION = None    # ボールキャッチ位置
    THROW_POSITION = -45.0   # 投擲位置
    RUN_POSITION = None     # 走行位置
    
    # ランチャーサーボ角度定数
    LAUNCHER_RELOAD = 180    # リロード位置
    LAUNCHER_READY = 30      # 待機位置
    LAUNCHER_FIRE = 0        # 発射位置
    
    def __init__(self, 
                 machine_id: int,
                 futaba_port='/dev/ttyAMA0', 
                 futaba_baudrate=115200,
                 arduino_port='/dev/ttyARM', 
                 arduino_baudrate=115200,
                 arm_servo_id=1,
                 arm_min_angle=-90.0,
                 arm_max_angle=45.0):
        """
        初期化
        
        Args:
            futaba_port: Futabaサーボのシリアルポート (Raspberry Pi 5では /dev/ttyAMA0)
            futaba_baudrate: Futaba通信速度 (デフォルト: 115200bps)
            arduino_port: Arduinoのシリアルポート
            arduino_baudrate: Arduino通信速度
            arm_servo_id: アームサーボのID (デフォルト: 1)
            arm_min_angle: アームサーボの最小角度 [度] (デフォルト: -90.0)
            arm_max_angle: アームサーボの最大角度 [度] (デフォルト: 45.0)
        """
        if machine_id == 1:
            Arm.CATCH_POSITION = 42.0
            Arm.RUN_POSITION = -90.0
        elif machine_id == 2:
            Arm.CATCH_POSITION = 45.0
            Arm.RUN_POSITION = -85
        # Futabaサーボ設定
        self.arm_servo_id = arm_servo_id
        self.arm_min_angle = arm_min_angle
        self.arm_max_angle = arm_max_angle
        self.futaba_serial: Optional[serial.Serial] = None
        
        # Arduino設定
        self.arduino_port = arduino_port
        self.arduino_baudrate = arduino_baudrate
        self.arduino_serial: Optional[serial.Serial] = None
        self.is_arduino_connected = False
        self.is_running = False
        
        # センサーデータ受信用
        self.sensor_data_queue = queue.Queue(maxsize=100)
        self.latest_sensor_data: Optional[SensorData] = None
        self.sensor_callback: Optional[Callable[[SensorData], None]] = None
        
        # スレッド用
        self.read_thread: Optional[threading.Thread] = None
        self.lock = threading.Lock()
        
        # Futabaサーボ接続
        try:
            self.futaba_serial = serial.Serial(
                port=futaba_port,
                baudrate=futaba_baudrate,
                bytesize=serial.EIGHTBITS,
                parity=serial.PARITY_NONE,
                stopbits=serial.STOPBITS_ONE,
                timeout=0.1
            )
            time.sleep(0.1)  # 安定化待ち
            print(f"Connected to Futaba servo on {futaba_port}")
        except Exception as e:
            print(f"Futaba servo connection failed: {e}")
            self.futaba_serial = None
    
    def connect_arduino(self) -> bool:
        """
        Arduinoに接続
        
        Returns:
            接続成功の場合True
        """
        try:
            self.arduino_serial = serial.Serial(
                port=self.arduino_port,
                baudrate=self.arduino_baudrate,
                timeout=1.0
            )
            time.sleep(2)  # Arduino初期化待機
            
            self.is_arduino_connected = True
            self.is_running = True
            
            # 受信スレッド開始
            self.read_thread = threading.Thread(target=self._read_loop, daemon=True)
            self.read_thread.start()
            
            print(f"Connected to Arduino on {self.arduino_port}")
            return True
            
        except Exception as e:
            print(f"Arduino connection failed: {e}")
            return False
    
    def disconnect(self):
        """すべての接続を切断"""
        # Arduino切断
        self.is_running = False
        self.is_arduino_connected = False
        
        if self.read_thread and self.read_thread.is_alive():
            self.read_thread.join(timeout=2.0)
        
        if self.arduino_serial and self.arduino_serial.is_open:
            self.arduino_serial.close()
            print("Disconnected from Arduino")
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

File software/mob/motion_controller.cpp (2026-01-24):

#include "motion_controller.h"
#include <math.h>

// Tuning constants (initial / placeholder)
static constexpr float DEFAULT_KP = 800.0f;
static constexpr float DEFAULT_KI = 60.0f;
static constexpr float DEFAULT_KD = 0.0f;

float MotionController::SpeedPID::step(float err, float dt_s) {
    if (dt_s <= 0) return 0.0f;
    integ += err * dt_s;
    float deriv = (err - prev_err) / dt_s;
    prev_err = err;
    float u = kp * err + ki * integ + kd * deriv;
    if (u > out_max) u = out_max;
    if (u < out_min) u = out_min;
    return u;
}

void MotionController::SpeedPID::reset() {
    integ = 0.0f;
    prev_err = 0.0f;
}

MotionController::MotionController(Motor& motor, Sensors& sensors)
    : motor_(motor), sensors_(sensors) {
    pid_r_ = {DEFAULT_KP, DEFAULT_KI, DEFAULT_KD, 0.0f, 0.0f, -255.0f, 255.0f};
    pid_l_ = {DEFAULT_KP, DEFAULT_KI, DEFAULT_KD, 0.0f, 0.0f, -255.0f, 255.0f};
}

void MotionController::update(uint32_t dt_ms) {
    apply_speed_pid(dt_ms);
}

void MotionController::forward(float speed_mps, float lateral_error) {
    mode_ = Mode::FORWARD;

    // Placeholder: lateral_error -> differential speed correction
    // Positive lateral_error means drifting right => slow right / speed up left (example).
    const float corr = k_lateral_ * lateral_error;
    set_targets_mps(speed_mps - corr, speed_mps + corr);
}

void MotionController::backward(float speed_mps) {
    mode_ = Mode::BACKWARD;
    set_targets_mps(-fabsf(speed_mps), -fabsf(speed_mps));
}

bool MotionController::turn_in_place(float speed_mps, float target_angle_rad) {
    // First call: capture start angle
    if (!turn_active_) {
        turn_active_ = true;
        turn_target_rad_ = target_angle_rad;
        turn_start_angle_rad_ = sensors_.get_angle();
    }

    mode_ = Mode::TURN;

    const float s = fabsf(speed_mps);
    if (target_angle_rad >= 0) {
        // turn left: right forward, left backward
        set_targets_mps(+s, -s);
    } else {
        // turn right
        set_targets_mps(-s, +s);
    }

    // Completion check (uses odometry angle)
    const float current = sensors_.get_angle();
    const float turned = current - turn_start_angle_rad_;
    if ((target_angle_rad >= 0 && turned >= target_angle_rad) ||
        (target_angle_rad < 0 && turned <= target_angle_rad)) {
        stop();
        turn_active_ = false;
        return true;
    }

    return false;
}

void MotionController::stop() {
    mode_ = Mode::STOP;
    set_targets_mps(0.0f, 0.0f);
    pid_r_.reset();
    pid_l_.reset();
    motor_.set_right_motor(0);
    motor_.set_left_motor(0);
}
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

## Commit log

2025-10-08 Add schematics of main board
    [main_board.kicad_pcb, main_board.kicad_sch, main_board_outline.dxf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]
2025-10-11 アートワーク : 部品配置
    [main_board.kicad_pcb, main_board.kicad_sch, power.kicad_sch]
2025-10-11 アートワーク : 部品配置完了
    [encoder_board_outline.dxf, main_board.kicad_pcb, main_board.kicad_sch]
2025-10-11 Add .gitignore for KiCad
2025-10-11 アートワーク : 部品配置微修正
    [main_board.kicad_pcb]
2025-10-11 アートワーク : 配線完了
    [main_board.kicad_pcb, main_board.kicad_sch, power.kicad_sch]
2025-10-11 アートワーク : 微修正
    [main_board.kicad_pcb]
2025-10-12 回路図 : 3.0Vから3.3Vに変更 アートワーク : コネクタピン配などのシルクを追加
    [main_board.kicad_pcb, main_board.kicad_sch, power.kicad_sch]
2025-10-17 部品名を修正
    [power.kicad_sch]
2025-11-05 定数や型番の修正
    [main_board.kicad_sch, power.kicad_sch]
2025-12-09 充電回路追加
    [main_board.kicad_pcb, main_board.kicad_sch, power.kicad_sch]
2025-12-11 部品名追加
    [main_board.kicad_sch, power.kicad_sch]
2025-12-12 アートワーク開始
    [main_board.kicad_pcb, main_board.kicad_sch, main_board_outline.dxf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]
2025-12-13 アートワークひととおり完成
    [main_board.kicad_pcb, main_board.kicad_sch, power.kicad_sch]
2025-12-13 Sub boardsの回路図作成
    [sub_boards.kicad_pcb, sub_boards.kicad_sch]
2025-12-13 サブ基板アートワーク完了
    [if_sub_board_outline.dxf, sensor_sub_board_outline.dxf, sub_boards.kicad_pcb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]
2025-12-13 アートワーク微修正
    [main_board.kicad_pcb, sub_boards.kicad_pcb]
2025-12-18 12/18 基板発注
    [if_sub_board_outline.dxf, main_board.kicad_pcb, main_board.kicad_sch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]
2025-12-27 メイン基板を製造用に出図
2025-12-27 サブ基板を製造用に出図
    [encoder_board_outline.dxf, if_sub_board_outline.dxf, sensor_sub_board_outline.dxf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]
2025-12-27 アーム基板WIP
    [arm_board.kicad_pcb, arm_board.kicad_sch]
2025-12-27 KiCadのプロジェクトファイルをelecディレクトリ以下に移動
    [arm_board.kicad_pcb, arm_board.kicad_sch, encoder_board_outline.dxf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]
2025-12-27 アームのテストプログラム
2025-12-27 スピード指定付きの角度設定コマンド
2025-12-28 アーム基板テストコード(test.py)
2025-12-28 ファイル実行中は電流値をグラフ表示する
2025-12-28 電流値の送信間隔を25msに変更
2025-12-28 自動でボールキャッチを検知して投げるテスト(throw_test.py)
2025-12-28 README.mdを更新
2026-01-02 ARMのフォルダにアーム関連のコードを移動
2026-01-02 Mobile platform(ESP32)のプロジェクトを追加
2026-01-02 if_pyとcamera_pyを追加
2026-01-02 KiCad用.gitignoreを修正
2026-01-02 サブボード（IFボード）を修正
    [sub_boards.kicad_pcb, sub_boards.kicad_sch]
2026-01-05 アームボードのモータードライバを変更
    [arm_board.kicad_sch]
2026-01-05 抵抗などの型番を指定
    [arm_board.kicad_sch]
2026-01-09 ARMボード発注
    [arm_board.kicad_pcb, arm_board.kicad_sch, arm_board_outline.dxf]
2026-01-12 Mobのファームウェアを追加
    - IMU
    - LED
    - Motor
    - Wall sensors
2026-01-12 Add encoder support to the mob software
2026-01-12 Mobボードの動作確認完了
2026-01-17 アーム基盤の動作確認
2026-01-17 カメラによるボール検出
2026-01-17 アームボードの動作確認
2026-01-17 センサをまとめて扱うsensorsクラスを追加
2026-01-18 RS204MDをUARTで操作するコード
2026-01-19 ARMボードから不要な回路を削除
    [arm_board.kicad_sch]
2026-01-24 オドメトリ追加、PC側のアプリ追加
2026-01-24 起動時の壁センサをオフに
2026-01-24 フタバのデジタルサーボを制御するコード
2026-01-24 ホイールベースの値を修正
2026-01-24 旋回コマンド追加
2026-01-25 足立法のPythonによる実装
2026-01-25 テストスクリプト改良
2026-01-25 テスト用の迷路データを追加
2026-01-26 SENを定期的に送るのではなく、PCからの要求に応じて送るように変更
2026-01-26 pc_comm.pyが起動時に壁センサをオンにし、終了時オフにするように変更
2026-01-26 回路図更新
    ・壁センサLEDの抵抗値を100Ωに変更
    ・電源スイッチを削除
    ・ESP32のENにプルアップ追加
    [main_board.kicad_pcb, main_board.kicad_sch, power.kicad_sch]
2026-01-27 FWDコマンドの距離累積バグ修正と信頼性向上
    主要な修正:
    - FWDコマンドの距離計算を修正（fwd_goal_dist_mmを+=から=に変更）
    複数のFWDコマンド間で目標距離が累積される問題を解決
    - RDSTとRANGコマンドにDONE応答を追加し、同期を確実に
    - FWDコマンド実行中の赤色LED表示を追加（実行中点灯、完了時消灯）
    - latency timerを設定するシェルスクリプトを追加
    改善点:
    - msg_queueサイズを32から128に増加してメッセージ損失を防止
    - enqueue_msg_line()に10msタイムアウトを追加してDONE送信を確実に
    - fwd.pyにシリアル例外ハンドリングを追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
    [fwd.py, mob.ino]
2026-01-27 ESP32のリセットスクリプトを修正
2026-01-27 FWDテストスクリプトとIMU設定を改善、ジャイロキャリブレーション機能を追加
    - fwd.py: FWD/STOPコマンドの速度・加速度パラメータを定数化し調整しやすく
    - fwd.py: GCALコマンドを追加してテスト開始前にジャイロキャリブレーションを実行
    - fwd.py: 入力バッファをクリアしてDONE応答の信頼性を向上
    - fwd.py: テストシーケンスを拡張（追加のRDST/RANG/FWD/STOPコマンド）
    - imu.cpp: ODRを6.66kHzから416Hzに変更してノイズを低減
    - imu.cpp: ジャイロ/加速度センサの設定を改善（自動インクリメント、ハイパフォーマンスモード）
    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
2026-01-27 IMUのジャイロ設定を±1000dpsに変更し、STOPコマンドの速度下限を20mm/sに設定
    - imu.cpp/.h: ジャイロスコープのフルスケールを±2000dpsから±1000dpsに変更
    - 感度が35 mdps/LSBに向上（分解能2倍）
    - マイクロマウスの旋回速度には±1000dpsで十分
    - mob.ino: STOPコマンドの最低速度を20mm/sに設定
    - 減速ロジックは維持しつつ、速度が20mm/s未満にならないよう制限
    - 目標距離到達時のみ停止してDONEを返す
    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
2026-01-27 壁センサーの差分計算で負の値を防ぐ
    - wall_sensor.cpp: LEDオフ時の値がオン時より大きい場合は0を返すように修正
    - lf(), rf(), ls(), rs()の4つの関数すべてで対応
    - uint16_tのアンダーフローを防止
    [wall_sensor.cpp]
2026-01-27 直進時の角度フィードバック追加
2026-01-27 fwd.py : マウスへコマンドを送るクラスを作成
2026-01-27 壁センサ（RS/LS）を用いた直進フィードバックをFWD/STOPに統合し、100未満は無効・両方有効時は平均、片側のみは片側のみの補正とするロジックを追加。中央基準値240に対する誤差から補正値を算出し、角度フィードバックと合算して直進安定性を向上。デバッグ出力で補正量の確認も可能にした。
2026-01-28 fwd.pyの制御クラスをMobileBaseに整理し、コマンド系メソッド名をcmd_*に統一。旋回角をπベースに変更し、右左/180度旋回や前後進などの高水準動作を追加。メインのテストシーケンスを簡潔化し、壁センサON/OFFやSEN取得の流れを整備。
2026-01-28 角速度フィードバック、STOP時のバックオフ
2026-01-28 低速連続動作コマンド(LFWD/LBACK/LTURNL/LTURNR/LSTOP)を実装
    - mob.ino: LatchMode状態機械を追加し、低速連続動作を実現
    - LFWD/LBACK: 50mm/sで連続前進/後退
    - LTURNL/LTURNR: 90deg/s相当で連続旋回
    - LSTOP: 低速動作の停止
    - 既存のFWD/STOP/TURNプロファイルとの競合を回避
    - fwd.py → mobile_base.pyに改名し、L*コマンドのメソッドを追加
    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
2026-01-28 探索走行実装
2026-01-28 ゴール時の壁情報が迷路情報に反映されない問題を修正
2026-01-28 ゴールしたときの壁情報がはんえいされていないばぐをしゅうせい
2026-01-28 バグ修正
2026-01-29 アーム基板v2の回路図＆アートワーク
    [arm_board.kicad_pcb, arm_board.kicad_sch]
2026-01-31 アームボードのグリッド原点を変更
    [arm_board.kicad_pcb]
2026-02-01 QSTPコマンド
2026-02-01 ボールの角度の距離推定（間違ってるようだ）
2026-02-01 futaba_servo.pyで角度指定できるように。角度リミット追加。
2026-02-07 ボールのキャッチ・投擲テスト
2026-02-07 迷路探索でゴールにたどり着けない場合のエラー処理を追加
2026-02-07 スレッド分割した探索
2026-02-07 走行中のボール検出
2026-02-07 カメラのウォームアップ廃止
2026-02-07 アーム制御用のスクリプトをarm.pyに統合
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2026-02-12 ボール検出キャリブレーション用GUIアプリを追加
    - manual_calibration.py: キャリブレーションデータ収集用GUI
    - リアルタイムカメラ表示、10回計測の中央値採用
    - 距離・角度の自動値更新で効率的なデータ収集
    - πラジアン単位での角度管理
    - アーム連携（起動時RUN_POSITION移動、終了時トルクオフ）
    - CALIBRATION_MANUAL.md: 詳細な操作マニュアル
2026-02-12 キャリブレーションデータ処理スクリプトを追加
    - generate_mirror_data.py: 左右対称データ生成スクリプト
    - 正の角度データから負の角度データを自動生成
    - カメラの左右対称性を仮定した補完
    - X座標の左右反転、角度の符号反転
    - 元データとマージして角度・距離でソート
    - データ統計情報の表示
    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
2026-02-14 マップ表示に歩数表示機能を追加。投擲位置の座標を修正。
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2026-02-14 バグ修正、
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
